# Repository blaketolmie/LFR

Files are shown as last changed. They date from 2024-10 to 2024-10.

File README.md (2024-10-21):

# LFR
ENMT221 Line Following Robot Software  
S2 2024  

## Access to Github
Send me your GitHub username or email so I can grant you collaborater access (so you can make push and pull requests etc)  
[GitHub Desktop](https://github.com/apps/desktop)

## Set up  
Download [MiniCore](https://github.com/MCUdude/MiniCore#how-to-install) and make sure its in the correct folder   
Open [Arduino IDE](https://www.arduino.cc/en/software)  
Select Board - ATmega328 and port  
Go to tools and select preferences and burn bootloader  
+ Board: "ATmega328"  
+ BOD (Brown-out detection): "BOD 2.7V"  
+ Bootloader: "Yes (UART0)"  
+ Clock: "Internal 1 MHz"  
+ Variant: "328P / 328PA"  
+ Programmer: "Atmel-ICE ISP"  
>**Arduino as ISP**: If you have an Arduino board, you can use it to program AVR chips by setting it up as an ISP (In-System Programmer). This is a common and cost-effective method.  
>USBasp: This is a popular and inexpensive USB-based programmer for AVR microcontrollers. It's widely used and works well with AVR GCC.  
>USBtinyISP: Another inexpensive USB programmer. It’s often used with AVR microcontrollers but might be slower than USBasp.  
>AVRISP mkII: This is an official programmer from Atmel (now Microchip) designed for use with AVR microcontrollers. It is a reliable choice if you have access to it.  
>Clock: 9.216 MHz  
>[Arduino Programming](https://docs.arduino.cc/programming/)  
>When coding in Arduino IDE use [Arduino Pins](https://camo.githubusercontent.com/b719fa994f4db0dd95e224fbdd939f93f7b6ba881b3c41e480b4733d4d82b6e6/68747470733a2f2f692e696d6775722e636f6d2f715849456368542e6a7067) in blue  
  
## Arduino_Code
Incorporated  
- Reactive control  
- LEDs  
- Sensors  
- Motors  
- Config file - all #defines for pin and globals  
- Serial communication (println)  
  
NOTE:  
Only one reset button (MOTOR_CONTROL) is available since the RESET button is not connect to the microcontroller in the schematic.  
If sensors are giving random values - check the height from the ground  
Only 3 sensors ended up working hence no PID or bang bang controller  
  
 ## ATMega328P Microcontroller
[ATMega328P Features Datasheet](https://components101.com/microcontrollers/atmega328p-pinout-features-datasheet)  
[ATMega328P Manufacteres Datasheet - register summary on pg8](https://www.jameco.com/Jameco/Products/ProdDS/2139111.pdf)

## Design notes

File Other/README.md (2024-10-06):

# LFR
ENMT221 Line Following Robot Software  
S2 2024  
[NOTE ON COLLABORATION](https://docs.github.com/en/pull-requests/collaborating-with-pull-requests/proposing-changes-to-your-work-with-pull-requests/about-pull-requests)

## ATMega328P Microcontroller
[ATMega328P Datasheet](https://components101.com/microcontrollers/atmega328p-pinout-features-datasheet)  
[Pinout with ADC pins explained](https://www.learningaboutelectronics.com/Articles/Atmega328-pinout.php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,value%3B%20thus%2C%20it%20is%20its%20digital%20correspondent%20value.)
[Full datasheet - register summary on pg8](https://www.jameco.com/Jameco/Products/ProdDS/2139111.pdf)  
## Downloading the bootloader (using Arduino IDE)
[Arduino IDE](https://docs.arduino.cc/software/ide/)    <br>
[MiniCore](https://github.com/MCUdude/MiniCore#how-to-install)  

Using Arduino as ISP since code is in Arduino
>To burn a bootloader using AVR GCC, the choice of programmer depends on the hardware you have available for interfacing with the microcontroller.  
>Here’s a breakdown of the programmers listed in your image and their common uses:  
>  
>**Arduino as ISP**: If you have an Arduino board, you can use it to program AVR chips by setting it up as an ISP (In-System Programmer). This is a common and cost-effective method.  
>USBasp: This is a popular and inexpensive USB-based programmer for AVR microcontrollers. It's widely used and works well with AVR GCC.  
>USBtinyISP: Another inexpensive USB programmer. It’s often used with AVR microcontrollers but might be slower than USBasp.  
>AVRISP mkII: This is an official programmer from Atmel (now Microchip) designed for use with AVR microcontrollers. It is a reliable choice if you have access to it.  
>Clock: 9.216 MHz  

## Programming CHANGE TO ARDUINO PROGRAMMING SINCE EASIER / FASTER
[Arduino Programming](https://docs.arduino.cc/programming/)  
>Serial.print(): Used to print data to the serial monitor without a newline.  
>Serial.println(): Used to print data to the serial monitor with a newline.  
>Serial.println("The value is: " + String(value));

[MiniCore Tips](https://github.com/MCUdude/MiniCore#how-to-install)  
[Embedded C](https://www.learningaboutelectronics.com/EmbeddedC/)  
[AVR](https://github.com/avrdudes/avr-libc)  
**More**  
[Microcontrollers](https://www.eng.auburn.edu/~nelson/courses/elec3040_3050/C%20programming%20for%20embedded%20system%20applications.pdf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)  
[Using ATMEL Studios](https://hardwarebee.com/step-by-step-guide-to-microcontroller-programming/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)  
[tutorial](https://github.com/a5221985/tutorials/blob/master/Embedded_Systems/microcontroller_embedded_c_programming_absolute_beginners.md)  
[other](https://github.com/aman-goel/avr)  
[ENCE260 Richard Claire Code](https://eng-git.canterbury.ac.nz/rmc84/ence260-ucfk4)  
### Pin macros
// Use PIN_PB5 macro to refer to pin PB5 (Arduino pin 13)  
digitalWrite(PIN_PB5, HIGH);

// Results in the exact same compiled code  
digitalWrite(13, HIGH);

### Other things of note with MiniCore
Printf support  
EEPROM option (Electrically Erasable Programmable Read-Only Memory)  
BOD option  
[ADC pins explained](https://www.hackster.io/yeshvanth_muniraj/analog-to-digital-converter-module-of-atmega328p-e255ea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)  
[More on ADCs](https://www.tspi.at/2021/07/15/atmegaavradc.html#:~:text=The%20ATMega328p%20and%20the%20ATMega2560%20offers)  
[Using the ATmega328P ADC Module](https://ece-classes.usc.edu/ee459/library/documents/ADC.pdf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)  
[building circuits](https://www.build-electronic-circuits.com/microcontroller-tutorial-part3/)  

### Example Code


[GitHub Flavored Markdown Spec](https://github.github.com/gfm/)

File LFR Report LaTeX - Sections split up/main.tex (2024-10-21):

\documentclass{article}

% Language setting
% Replace `english' with e.g. `spanish' to change the document language
\usepackage[english]{babel}

% Set page size and margins
% Replace `letterpaper' with `a4paper' for UK/EU standard size
\usepackage[a4paper,top=2cm,bottom=2cm,left=2cm,right=2cm,marginparwidth=2cm]{geometry}

% Useful packages
\usepackage{amsmath}
\usepackage{graphicx}
\usepackage[colorlinks=true, allcolors=black]{hyperref}
\usepackage{bm}
\usepackage{float}  
\usepackage[utf8]{inputenc}
\usepackage{cite}

\usepackage{siunitx}
\usepackage{booktabs}
\usepackage{lipsum}%% a garbage package you don't need except to create examples.
\usepackage{fancyhdr}
\pagestyle{fancy}
\lhead{Wednesday Group A}
\rhead{Line Following Robot}

\renewcommand{\headrulewidth}{0.4pt}
\renewcommand{\footrulewidth}{0.4pt}

\title{%
  \textbf{Line Following Robot} \\
  \large{ENMT221-24S2} \\}
\author{Sarah Tran \\Blake Tolmie \\George Adams \\Michelle Wang }

\begin{document}
\begin{figure}
\centering
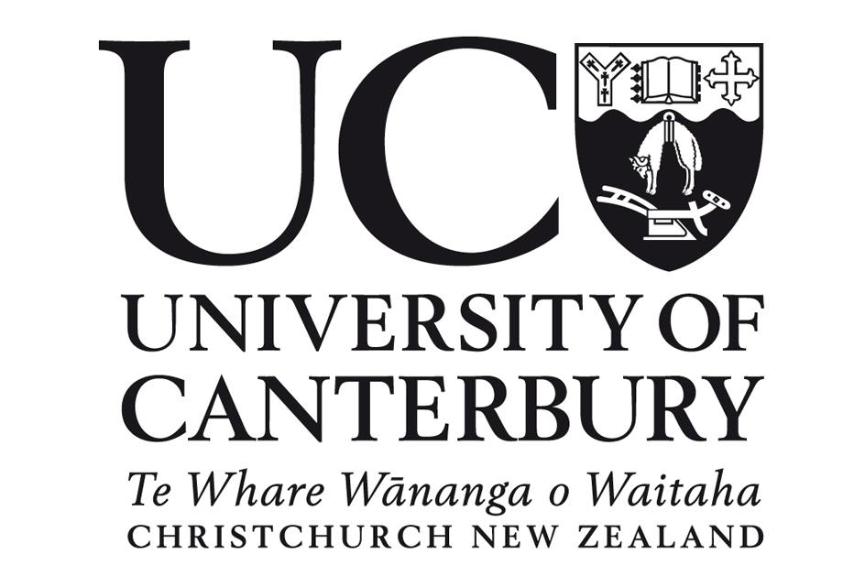
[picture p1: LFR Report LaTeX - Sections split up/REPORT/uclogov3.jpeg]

\end{figure}

\maketitle

\newpage
\begin{abstract}
This report presents the design, development, and performance analysis of a Line Following Robot (LFR), created as part of the ENMT221-24S2 term 4 project. The goal was to design a robot capable of autonomously navigating a course, following a black line on a white background, under strict design and time constraints. The process involved circuit and PCB design, mechanical prototyping, and microcontroller programming. Challenges encountered during the project included sensor board issues, requiring multiple adjustments and iterative design refinements. The final design demonstrated competitive performance, completing the course in 14.939 seconds and coming in $8^{th}$ place out of 36 teams. Despite successful results, further improvements in sensor integration and control algorithms, such as transitioning to PID control, are suggested to enhance the robot's tracking accuracy and speed. This project provided valuable hands-on experience with real-world testing, electronic design, and mechanical assembly.
\end{abstract}

\newpage
\tableofcontents

\newpage
\section{Introduction}
Automation is becoming increasingly prevalent in modern technology, especially with the rise of artificial intelligence and high labour costs. As mechatronics engineering students, it is important to have a strong understanding of the concepts surrounding this. For the term 4 project, we were tasked to design a line-following robot (commonly abbreviated as ‘LFR’) under the given constraints and limitations as specified by the project brief \cite{enmt221_lfr2024}. This process involves circuit design, PCB layout and manufacturing, mechanical design, and microcontroller programming. The aim was to design a robot that completes the provided course (black line on white background) in under 30 seconds. Line following robots have some real-world applications, such as the transportation of medical equipment in large hospitals \cite{kumaresan2017line}, and autonomous public transport \cite{gumus2016line}.  

\include{Contents/methodology.tex}
\include{Contents/results_and_discussion.tex}

\section{Conclusion}
 The Line Following Robot project involved circuit design, PCB layout, mechanical assembly, and control systems. While we encountered challenges, particularly with sensor board malfunctions and feedback control, the robot still performed well, completing the course in 14.939 seconds. By using a reactive control system, we were able to achieve consistent results, though transitioning to a PID control system could improve accuracy and make the robot’s movements smoother. This project emphasized the importance of testing and collaboration to work through design unpredicted errors. Moving forward, further improvements could be made by refining sensor placement, improving the control system, and optimizing the mechanical design. Overall, the project met its objectives and gave us practical experience in combining different areas of mechatronics engineering.

\newpage
\section{references} % Makes it so then it shows up in the table of contents
\bibliographystyle{ieeetr}  % The style of the bibliography (e.g., plain, alpha, etc.) 
\bibliography{Contents/references}

\newpage
\include{Contents/appendix.tex}

\end{document}

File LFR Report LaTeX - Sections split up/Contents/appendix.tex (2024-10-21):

\appendix
\section{Arduino Code for Line Following Robot}
\subsection{Overview}
The code was programmed using Arduino. Only the .ino, .cpp and config.h files are included in Appendix B. For full code including .h files, access the GitHub: \href{https://github.com/blaketolmie/LFR}{https://github.com/blaketolmie/LFR}
\subsection{LFR\_Main.ino}

\begin{figure}[H]
    \centering
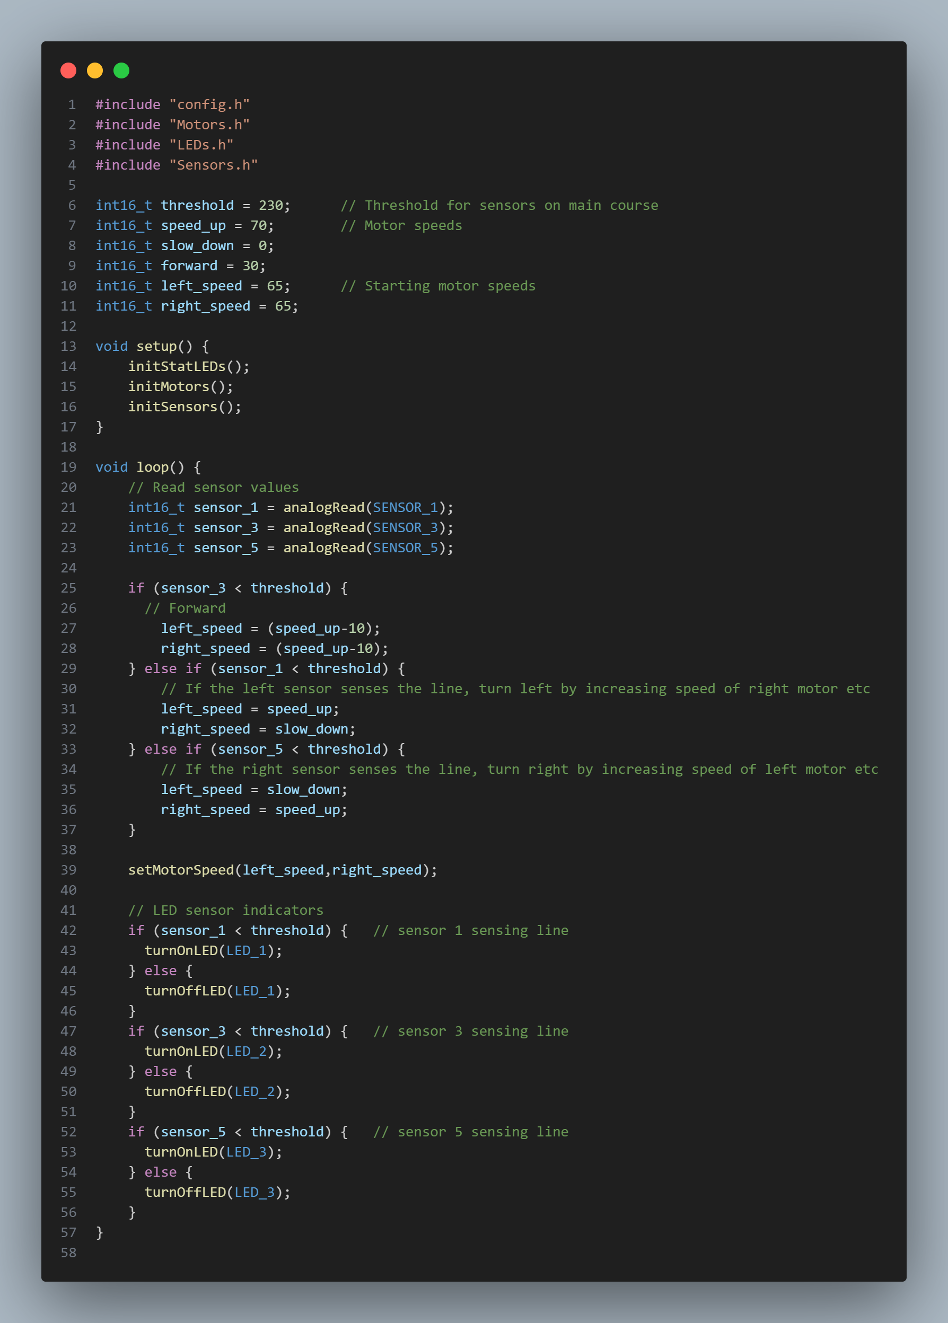
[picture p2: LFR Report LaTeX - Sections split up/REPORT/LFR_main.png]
    
\end{figure}

\subsection{Motors.cpp}

\begin{figure}[H]
    \centering
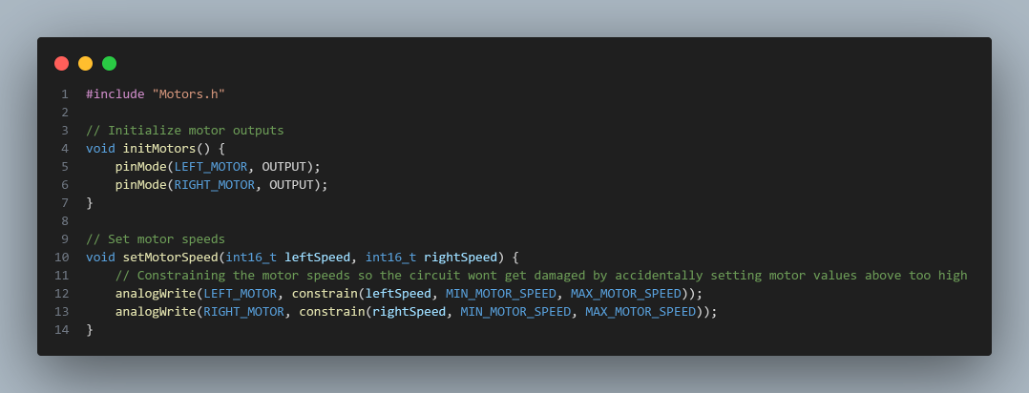
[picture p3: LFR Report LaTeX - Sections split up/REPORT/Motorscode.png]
    
\end{figure}

\subsection{Sensors.cpp}

\begin{figure}[H]
    \centering
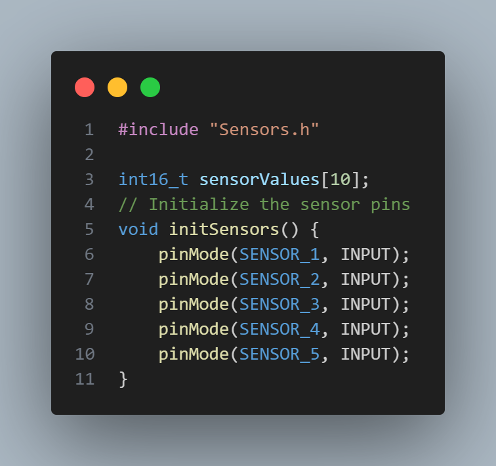
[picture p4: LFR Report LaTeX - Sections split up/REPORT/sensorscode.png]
    
\end{figure}

\subsection{LEDs.cpp}

\begin{figure}[H]
    \centering
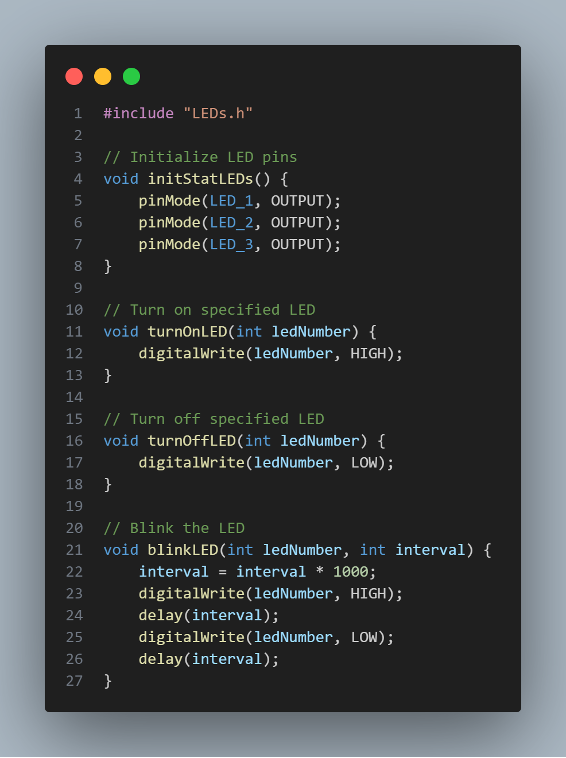
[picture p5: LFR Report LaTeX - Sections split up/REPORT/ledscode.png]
    
\end{figure}

\subsection{Config.h}

\begin{figure}[H]
    \centering
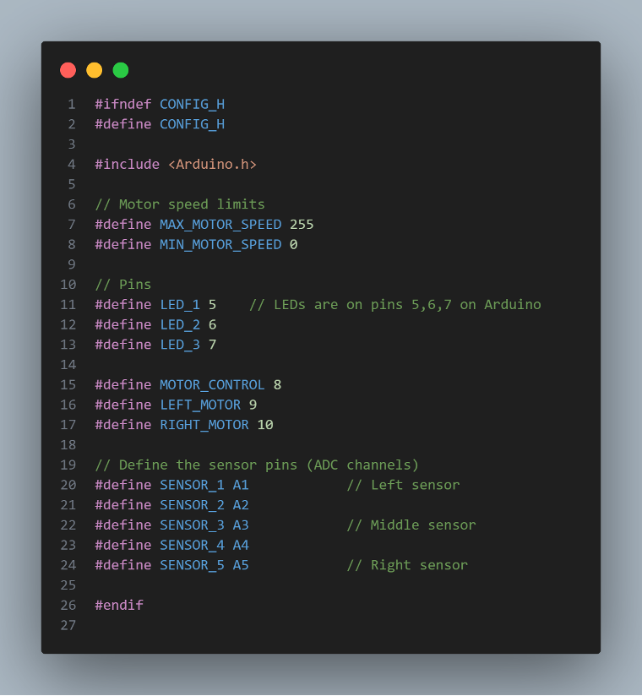
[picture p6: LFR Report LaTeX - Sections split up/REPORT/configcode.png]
    
\end{figure}

\section{Table for LFR Course Times by Sensor Configurations and Weight}
\begin{figure}[H]
    \centering
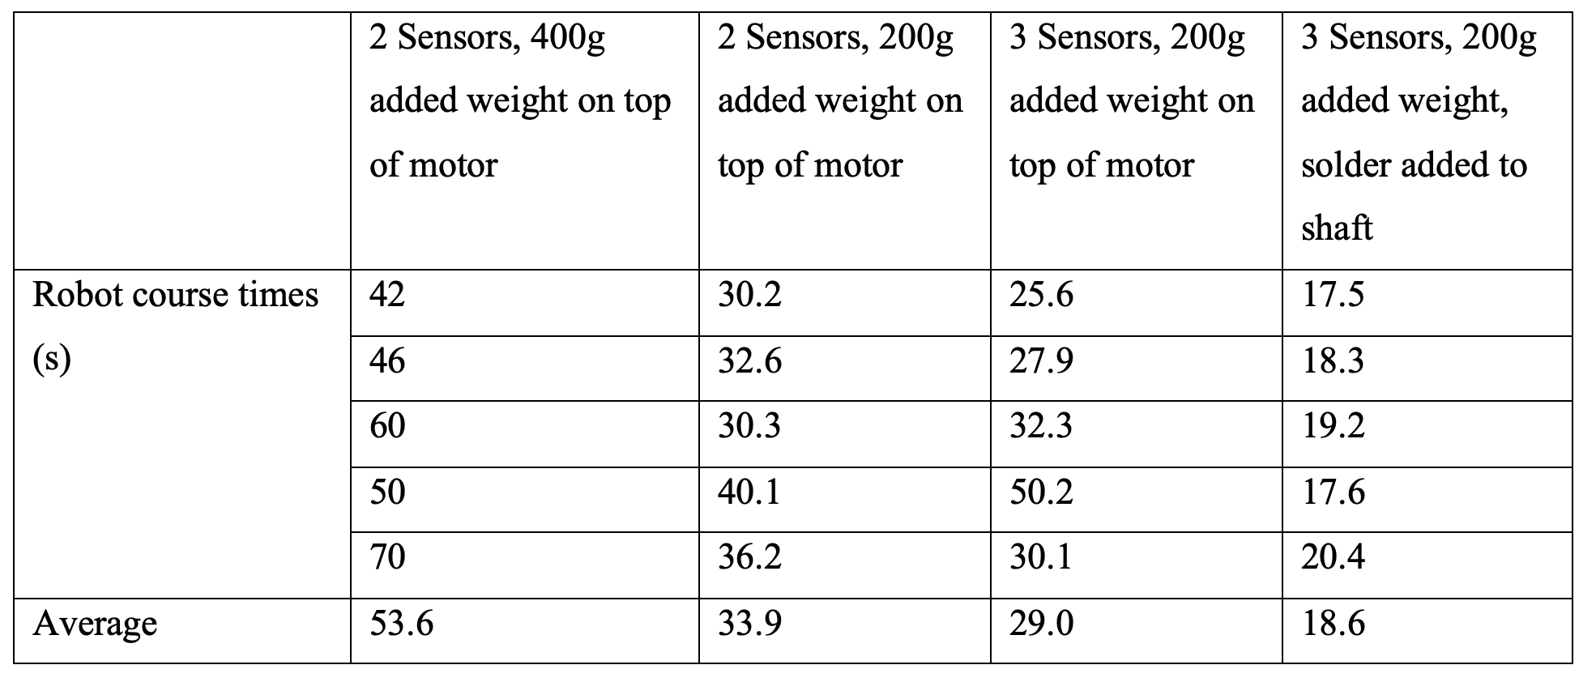
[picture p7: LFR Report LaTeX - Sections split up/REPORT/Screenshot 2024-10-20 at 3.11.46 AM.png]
    
\end{figure}

\section{Allowed Electronic Components}
\begin{figure}[H]
    \centering
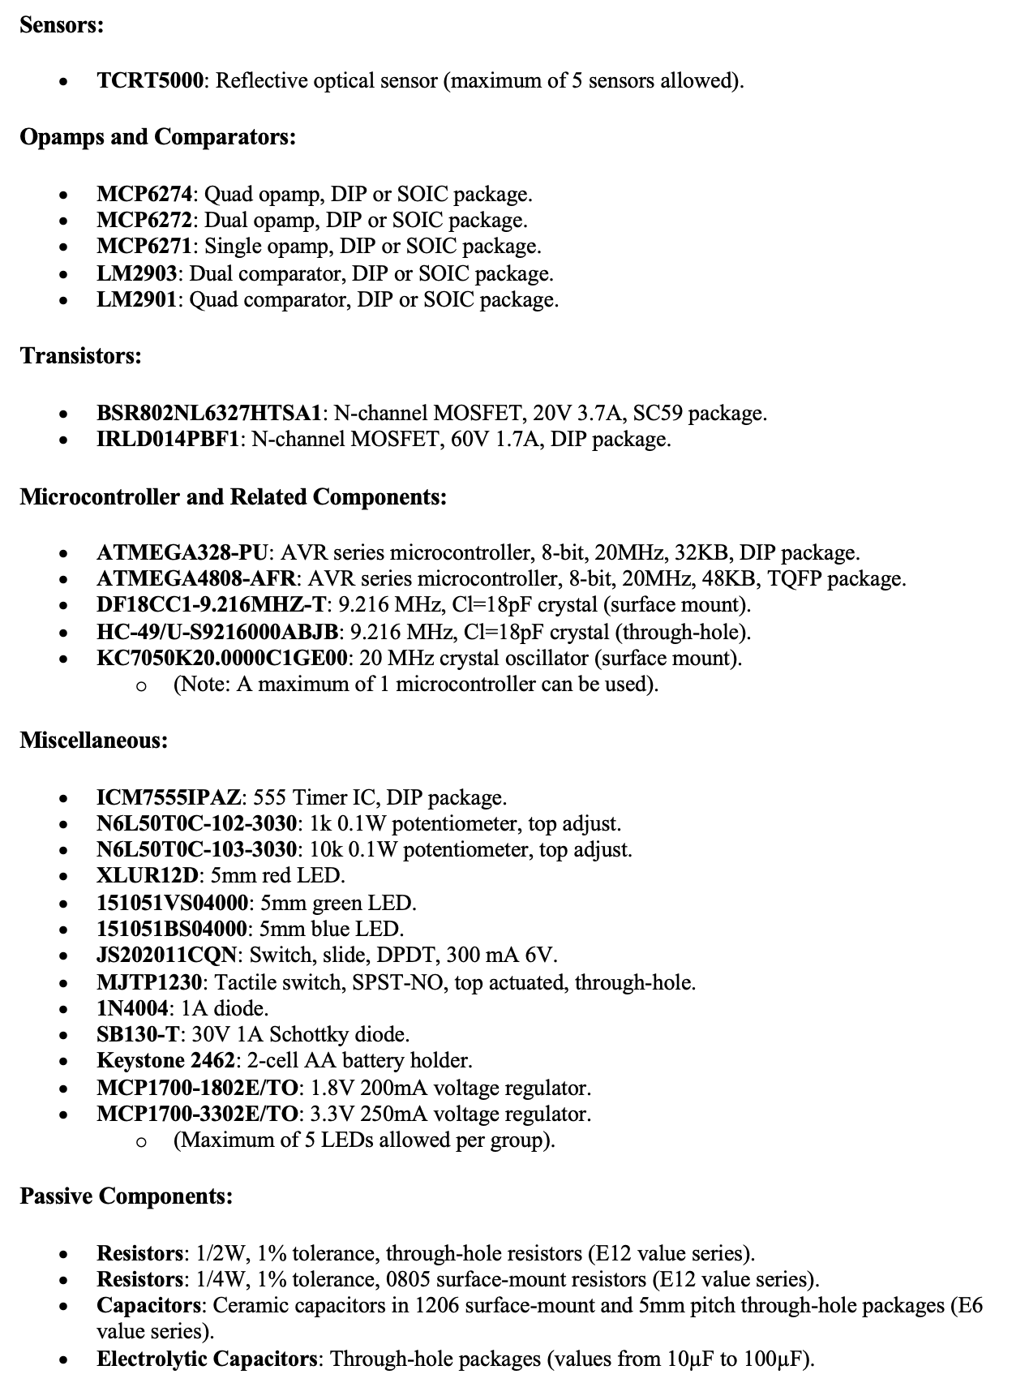
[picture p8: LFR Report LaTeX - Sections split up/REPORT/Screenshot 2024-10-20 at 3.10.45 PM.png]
    
\end{figure}

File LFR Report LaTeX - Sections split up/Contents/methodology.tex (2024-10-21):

\section{Methodology}
\subsection{Circuit Design}
Early in the design process, it was decided that the circuit would be split into a main PCB board and five separate sensor boards. This allowed the sensors to be moved during the mechanical design process, and the distance between them and the ground to be optimised through testing. The design process was split into smaller tasks and delegated to separate teammates. These tasks included motor drivers (Figure \ref{fig:MotorControlCircuit}), power regulation (Figure \ref{fig:VoltageinandReg}), sensors (Figure \ref{fig:SensorSchem}), programming interface and external oscillator (Figure \ref{fig:Crystal}), the microcontroller (Figure \ref{fig:Microcontroller}), and buttons \& LEDs (Figure \ref{fig:RSET}, \ref{fig:led}, and \ref{fig:Motor ON}).
\\

As collaboration was necessary, a major consideration of the design process was the use of the 'labels' function in KiCad, which can link two parts of a schematic together with an invisible virtual wire, to ensure smooth compatibility between systems. Another consideration was the restriction on allowed components (Appendix C), put in place to ensure fairness among teams.

\begin{figure}[H]
    \centering
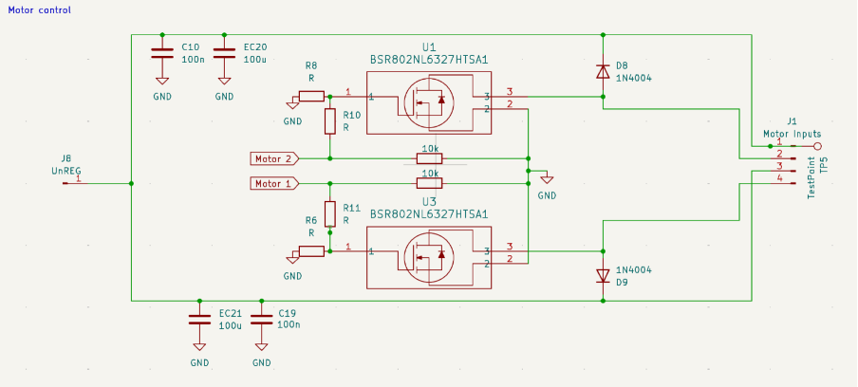
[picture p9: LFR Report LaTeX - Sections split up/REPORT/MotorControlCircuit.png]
    
    \caption{Motor Control Circuit}
    \label{fig:MotorControlCircuit}
\end{figure}

As seen in Figure \ref{fig:MotorControlCircuit}, the motors are controlled by MOSFETs which restrict and allow the flow of power from the unregulated power source through the motors to ground, depending on the input from Motor 1 and 2. These symbols are connected directly to an output capable pin of the microcontroller. As the motors are connected directly to the unregulated power source, capacitors C10, C19, EC20, EC21 are used to filter out unwanted high and low frequencies from the battery source. This use of capacitors is called decoupling. (Note here that C stands for ceramic capacitor which have high capacitance values, while EC stands for electrolytic capacitor which have small values). The motors interface with the circuit through connector J1. Pins 1 and 3 connect directly to the unregulated power source, and to the positive terminals of the motors when assembled. Pins 2 and 4 go to the source pin of the MOSFET and connect to the negative terminals of the motor. As the drain of the MOSFET is connected to ground, when a 3.3V signal comes from the pins of the microcontroller, the unregulated voltage will have a path through the motors to ground, enabling current flow. Flyback diodes D8 and D9 are connected from the MOSFET source pin to the unregulated voltage line, providing a path for back EMF of the motors to cycle through the motor, eventually reducing to 0V and protecting the rest of the circuit from unwanted voltage. 
\\

\begin{figure}[H]
    \centering
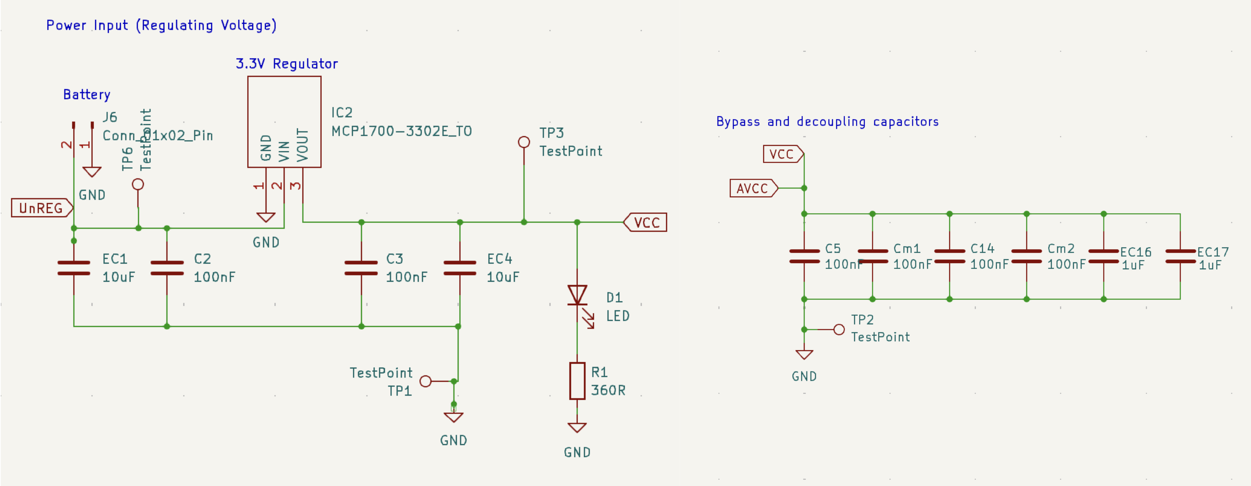
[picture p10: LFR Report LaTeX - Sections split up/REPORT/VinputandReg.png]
    
    \caption{Voltage input and regulation}
    \label{fig:VoltageinandReg}
\end{figure}

Figure \ref{fig:VoltageinandReg} shows how power comes into the circuit. A pack holding four AA batteries was connected to connector J6 labelled ‘Battery’. This was expected to output ~5.5 volts with some fluctuation. This was too high for safe operation of the microcontroller, and with sensitive components such as sensors, we needed some way of reducing the voltage to a manageable level and smoothing it out. The other pin of the battery pack is connected to common ground. After leaving the motor, the unregulated voltage is filtered through decoupling capacitors EC1 and C2 before entering the voltage regulator, IC2. This component outputs VOUT which connects through more decoupling capacitors, C3 and EC4, to the label VCC which is used throughout the circuit as the main power source. Between VCC and ground is a green LED which is used as a ‘power light’ as an easy way to check if the power source is operating correctly. Additionally, there are two test points for unregulated and regulated voltage to help with debugging and circuit analysis. 
\\

\begin{figure}[H]
    \centering
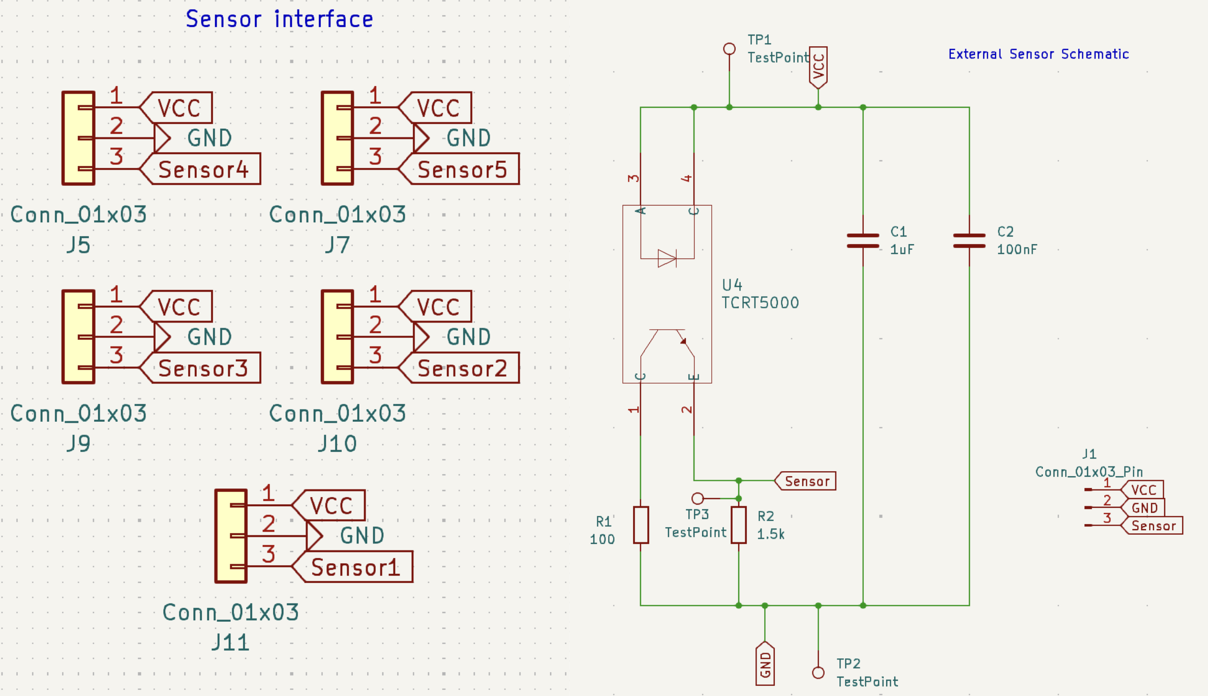
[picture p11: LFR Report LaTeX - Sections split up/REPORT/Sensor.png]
    
    \caption{Sensor board schematic and interface with main board}
    \label{fig:SensorSchem}
\end{figure}

The right section of Figure \ref{fig:SensorSchem} shows the schematic for the external sensor, and the left shows how it interfaces with the main PCB board. J5, 7, 9, 10 are all 3 pin connectors which have traces to VCC, GND and an input capable pin of the microcontroller, denoted by the labels Sensor1-5. These 3 pin connectors are mirrored on the sensor board with J1, allowing wires to be connected directly between the two boards. 
\\

C1 and C2 are decoupling capacitors which take out what little noise there may be from the voltage source. R1 and R2 are current-limiting resistors which prevent a short from output pins of the sensor to ground. It was discovered after the board was manufactured that this schematic was incorrect; Pins 1 and 3 should be connected to VCC, while 2 and 4 should be connected through R1 and R2, respectively, to ground. These modifications would allow current to flow through the BJT and LED inside the sensor and allow it to operate correctly. 
\\

Early in the design process, there was an idea to use an op-amp connected as a Schmitt trigger to convert the analogue output from the sensor to digital directly on the sensor board. After discussion with teaching assistants and other students, it was decided that the complications and possibilities for error of this design outweighed its benefits. 

\begin{figure}[H]
    \centering
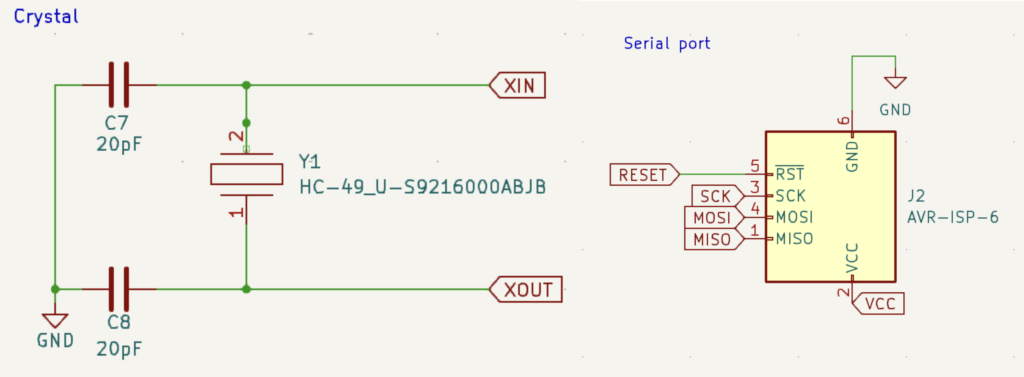
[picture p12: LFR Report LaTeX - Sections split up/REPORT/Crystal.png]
    
    \caption{Programming interface and crystal oscillator}
    \label{fig:Crystal}
\end{figure}

The microcontroller that was selected, the ATMEGA328, was a through-hole-mounted component. The other possibility, the ATMEGA4808, was surface-mount. As surface mount components require extreme delicacy to install correctly, it was decided that the ATMEGA328 would be used as it would ensure ease of assembly. As time constraints were one of the major considerations, this was the deciding factor. The downside of the 328 is that the internal oscillating clock used for timing operations is not ideal and is sometimes unreliable. Due to this, an external oscillating crystal was used. This is shown on the diagram as component Y1 which is connected from the XIN and XOUT pins of the microcontroller, through a set of high-frequency decoupling capacitors to ground. 
\\

The programming interface was implemented through a 6-pin connector, J2. This takes as inputs: A serial clock signal, MOSI and MISO communication channels, RESET, VCC and ground. 

\begin{figure}[H]
    \centering
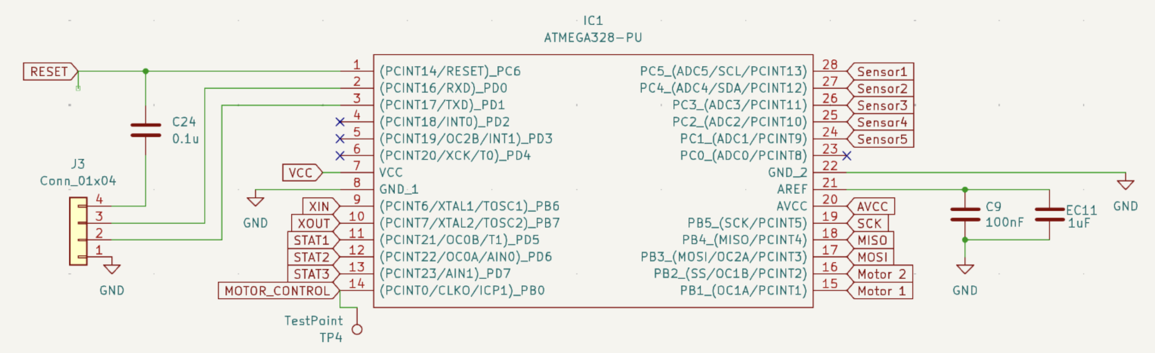
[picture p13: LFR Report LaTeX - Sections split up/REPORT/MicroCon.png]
    
    \caption{Microcontroller}
    \label{fig:Microcontroller}
\end{figure}

\begin{figure}[H]
    \centering
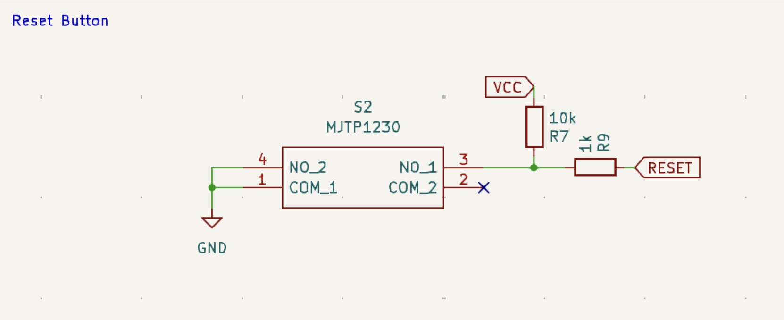
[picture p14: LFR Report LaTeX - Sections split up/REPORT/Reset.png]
    
    \caption{Reset button}
    \label{fig:RSET}
\end{figure}

\begin{figure}[H]
    \centering
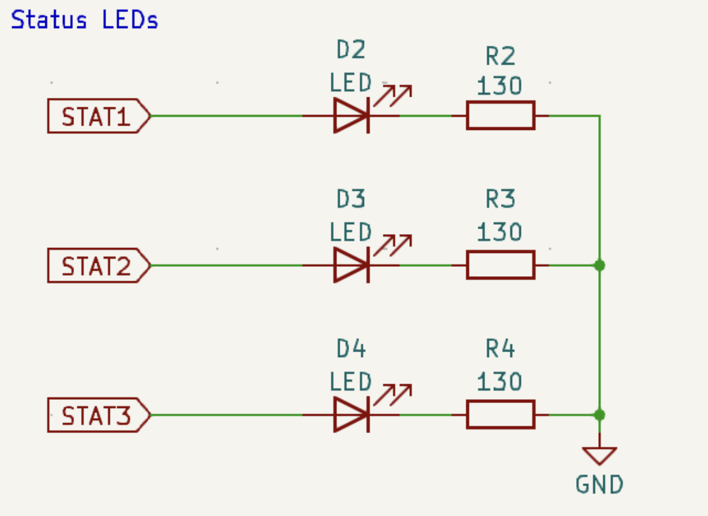
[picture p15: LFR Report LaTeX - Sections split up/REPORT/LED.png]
    
    \caption{Status LEDs}
    \label{fig:led}
\end{figure}

\begin{figure}[H]
    \centering
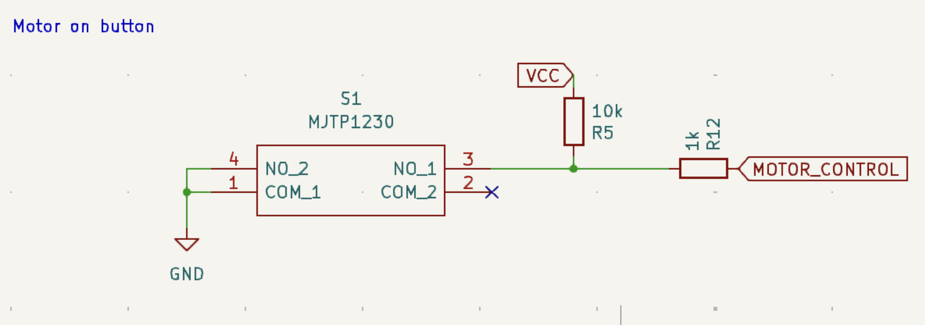
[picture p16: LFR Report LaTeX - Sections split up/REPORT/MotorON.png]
    
    \caption{Motor ON button}
    \label{fig:Motor ON}
\end{figure}

The two buttons - S1 and S2 in Figure \ref{fig:led} and \ref{fig:Motor ON}, were used to turn the motors on and reset the microcontroller, respectively. The VCC flag connects through resistors R7 and R5 to the input pins of the button and through R12 and R9 to ‘active low’ pins of the microcontroller. When the button is not pressed, VCC is able to flow through resistance to the microcontroller, providing it with the full 3.3V of regulated voltage. When the button is pressed, VCC is given a path to ground and shorts past the microcontroller, dropping it to 0V. At least, this is how it was designed. After assembling the board, it was found that the switches used, when pressed, connected pins 4 to 1 and 3 to 2. This meant that the voltage from VCC never had a path to ground, and thus the voltage on the microcontroller pin never dropped to 0. This issue was fixed by connecting a wire between pins 2 and 1, which allowed the button to function correctly. 
\\

The LEDs, shown in the right-hand side of Figure 5, were connected to output-capable pins of the microcontroller, enabling them to be controlled by code. As there was no way of printing outputs to check values of variables, these LEDs were invaluable in the programming stage of the project. 
\\

Finally, the microcontroller with all connected labels is shown in Figure \ref{fig:Microcontroller}. Another communication protocol (that wasn’t used) is seen in J3, which is connected to the RX and TX pins on the microcontroller, enabling a UART communication protocol.  
 
\subsection{PCB Design}
The PCB design for the main board was carried out in several stages. An initial layout (Figure \ref{fig:initpcb}) was completed to get an idea for how components might be arranged. 

\begin{figure}[H]
    \centering
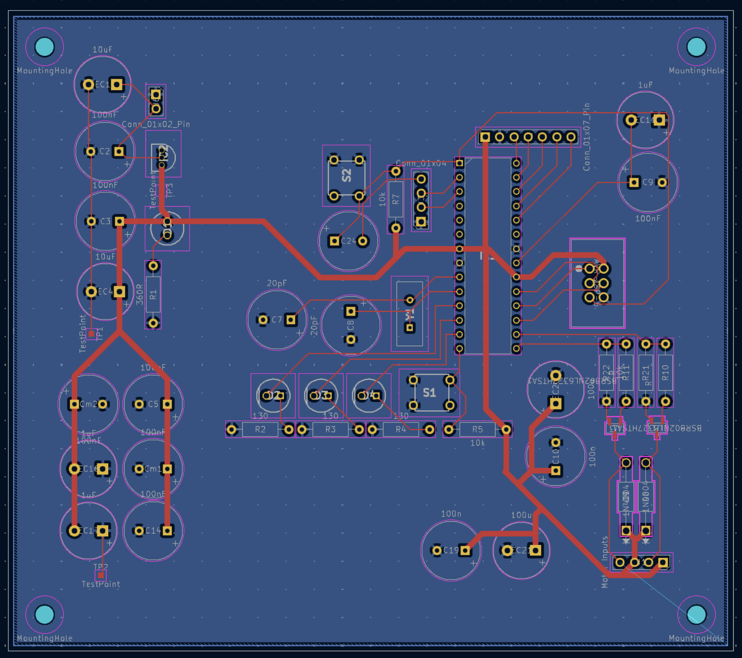
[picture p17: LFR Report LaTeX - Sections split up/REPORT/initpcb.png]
    
    \caption{Initial main PCB design}
    \label{fig:initpcb}
\end{figure}

The initial design took little consideration to the size of the final board. This was mostly an exercise in learning the workflow of KiCAD PCB design and was used to get feedback to complete a second, third and final iteration, which shown in Figure \ref{fig:finalpcb}. 

\begin{figure}[H]
    \centering
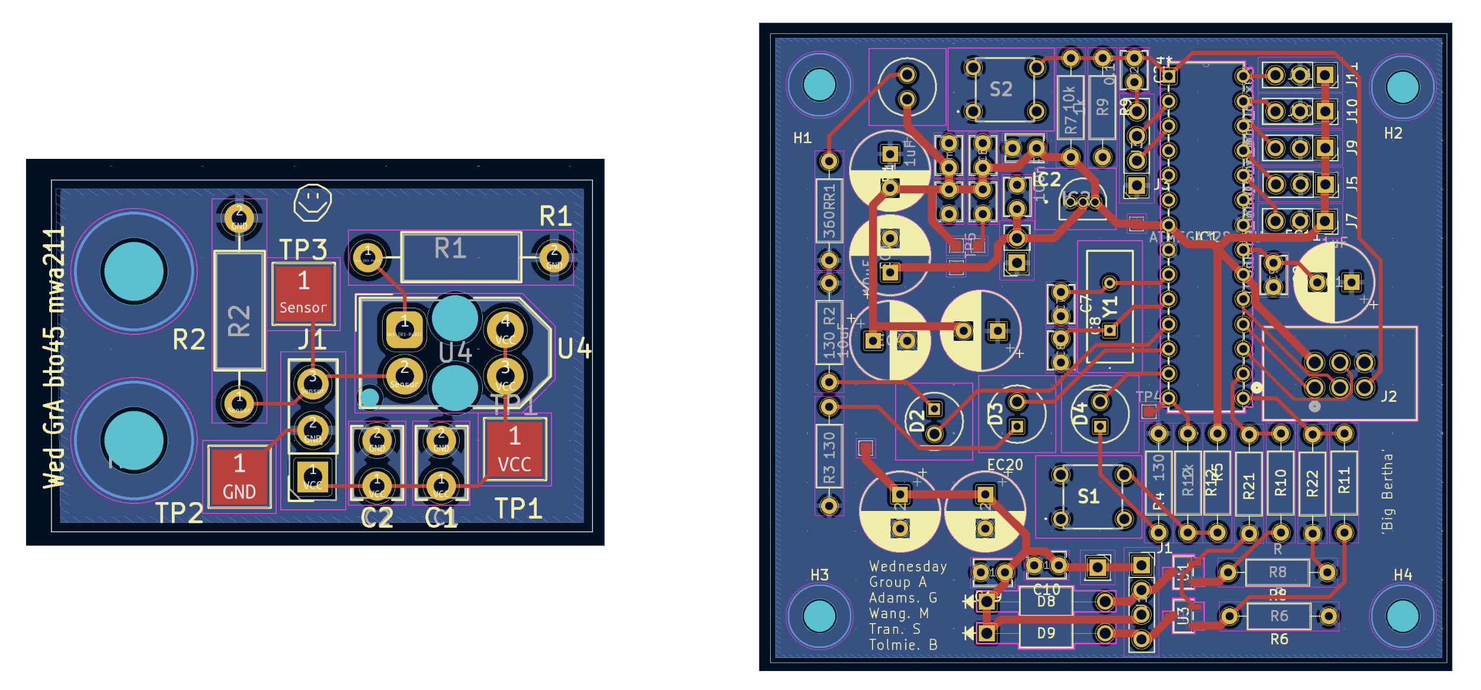
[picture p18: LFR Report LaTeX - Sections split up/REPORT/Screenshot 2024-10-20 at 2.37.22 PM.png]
    
    \caption{Final PCB designs}
    \label{fig:finalpcb}
\end{figure}

There were many considerations that went into the final design. The biggest of which was making traces as short as possible, which cut down on both the size of the board, and the amount of noise induced by electrical and magnetic field coupling. The second was keeping decoupling capacitors as close to the origin of their input signal as possible, to cut down on lag induced by the signal travel time and therefore increase their effectiveness. Finally, the size of the traces was considered, as higher current wires need thicker traces to ensure smooth operation. All wires carrying VCC were .8mm and larger, while all smaller signal carrying traces were left at .4mm. A few issues were encountered in selecting the incorrect footprints, as these were not provided alongside the list of allowable components. Through consultation with teaching assistants, the errors were found and corrected. 
\\

Once the design was completed, the Gerber files were extracted from KiCad and sent to JLC to be manufactured in China. This put pressure on the design process as the factory where they were being made shut down from the 1st to the $8^{th}$ of October. After some delegation and late nights, the completed boards were sent away on the $30^{th}$ of September and were received ready for assembly shortly after. 
\\

Comparatively, the sensor PCB board went through little iterations, the main changes being removing the Schmitt trigger and changing the layout to be smaller. The final design is shown alongside the main board in Figure \ref{fig:finalpcb}. 

\subsection{PCB Board Assembly}
We primarily utilised soldering irons for the PCB board assembly to solder on all the components. There are some key considerations we had to consider to ensure effective soldering.  
\\

We maintained a soldering temperature of 350 °C for all components, as this temperature allows the solder to melt quickly and adhere well to the surfaces being joined, ensuring a strong bond while minimizing excessive heat exposure. Many components, particularly sensitive electronics, can be damaged by higher temperatures, so 350 °C strikes a suitable balance by providing adequate heat for effective soldering while reducing the risk of overheating.  
\\

Additionally, this temperature promotes good flow characteristics, enabling the solder to wick into the gaps between pins and pads effectively. It also reduces the likelihood of oxidation on the surfaces being soldered, resulting in better wetting and bonding.  
\\

Since most components on our board are through-hole type, we utilized conical and chisel tips, depending on the size of the components. Like, we used a fine conical tip to minimize the risk of overheating. These tip shapes facilitate good heat transfer and allow for precision work, making detailed soldering on smaller components easier. The tapered shape of the tips enables access to tight spaces on the PCB without accidentally contacting other components, enhancing control and reducing the likelihood of soldering damage. 
\\

To ensure decent soldering quality, we also kept the soldering tip clean and tinned for efficient heat transfer, minimized the contact time to prevent damage to sensitive components like LEDs, and tested the connections with a multi-meter after soldering to ensure all the components were functioning correctly. 

\subsection{Main board adjustments}

During the testing stage, we encountered that the electrolytic capacitors were not directional which can lead to potential overheat, leakage, or even explosion due to internal pressure buildup. The polarization of these capacitors was random, which compounded the problem.  
\\

Additionally, the LED failed to turn on despite correct pin connections according to the ATMEGA328 micro-controller data sheet and the code for driving the LED. Upon a review of the main PCB layout against the schematic file, it was revealed that the issues were caused by incorrect footprints on the KiCAD PCB layout. In our case, some potential reasons could cause the incorrect footprints for the capacitors and LED. First, component rotation during the placement process may have inadvertently flipped certain components. To address this problem, we need to ensure that we check the orientation during placement and compare it with the schematic file when drawing the traces, making sure that everything is connected to the correct pin.  
\\

Second, incorrect pin mapping may have occurred if the pins on the schematic did not align correctly with the pads in the footprints. This misalignment can potentially lead to improper placement when generating the PCB layout.  
\\

Lastly, the schematic annotation may have played a role in the mismatch between the schematic and layout. It is essential to ensure that any changes made to the schematic file are promptly updated in the PCB layout to maintain consistency between the two. 
\\

Another issue that occurred in the main board assembly was the button connection, stemming from a misunderstanding of its configuration. The button features four pins, consisting of two short pins and two long pins. We incorrectly connected the button to the long pins instead of the short pins, which resulted in the button failing to complete the circuit correctly. To address this issue, we connected a wire between the long pins, so the button is now integrated into the circuit using the short pins. This way, when we press the button, it shorts to ground, allowing the circuit to function as intended. 

\subsection{Sensor board adjustments}
Figure \ref{fig:SensorAdjust} shows the layout of our sensor PCB board, along with the adjustments made based on the testing results. During the testing stage, we used a multimeter to measure the analog readings by testing the sensor pad against the ground pad. It became evident that there was no voltage drop when we covered the sensor, indicating that there was no detection of any objects. This lack of response marked the importance of precise pin connections for the TCRT500 sensor to ensure optimal functionality. 

\begin{figure}[H]
    \centering
    
    \caption{Sensor PCB Board layout adjustment}
    \label{fig:SensorAdjust}
\end{figure}

Upon reviewing the datasheet during the testing stage, we identified that there were some significant misconfigurations in our PCB layout. The Emitter-Cathode (pin 3 in Figure \ref{fig:SensorAdjust}) was not connected correctly with ground, impeding the current flow for the activation of the photo-transistor. To address this issue, we have made several modifications.  
\\

Firstly, we searched the traces connecting the Emitter-Cathode to the power source (VCC) and reconnected it to ground using a jumping wire. This change would allow proper current flow when the phototransistor is activated. 

Next, we scratched the traces between the Emitter-Cathode and Emitter-Anode, then connected the Emitter-Anode (pin 4 in Figure \ref{fig:SensorAdjust}) to VCC test pad with a 3.3k resistor. This modification provided a proper voltage drop and limited excessive current through the phototransistor. 

Additionally, we cut the connection between resistor R1 and the Phototransistor-Emitter (Pin 1) and reconnected the Phototransistor-Emitter to the VCC test pad using a 47 Ohms resistor. This adjustment ensures that the phototransistor is driven high when not active, facilitating correct circuit operation.  

Finally, we connected the Phototransistor-Collector (pin 2 in Figure \ref{fig:SensorAdjust}) to a pull-up resistor R2, leading to the positive voltage source. This would ensure a stable high signal when the phototransistor is off, preventing false readings.  
\\

These modifications are essential for restoring the functionality of TCRT500, ensuring the accurate detection capabilities for the Line following robot. 

\subsection{Mechanical design}
For the mechanical build, the following materials are allowed: 

\begin{itemize}  
    \item 100g of 3D printed PLA to be 3D printed.   
    \item Perspex sheet 4.5 mm thick with a bounding box of 200 × 200 mm.   
    \item M3 screws, washers, and nuts. 
    \item Rubber bands, thread. 
    \item Purely decorative elements. 
    \item Multicomp MM10 DC motor.
    \item Multicomp MM28 DC motor.
\end{itemize}  
The robot is fully printed from PLA using Bambu 3D printers from the University of Canterbury Mechanical Engineering Department. This method allows for rapid ideation and prototyping, allowing the design to be fine-tuned throughout the project.  

\subsubsection{Main Body}
The main body must serve as a base to attach the main PCB, sensor PCB modules, battery packs, wheels, and motor hinges. Initially, the main body was planned to be laser cut from an A3 Perspex acrylic sheet so that the 100g of printed PLA can be allocated to solely the wheels and motor hinges. The weight limit, however, was not an issue, and PLA was used for the main body as it allowed for decorative details and rapid prototyping (access to 3D printing is 24/7).  
\\

As shown in Figure \ref{fig:MainBod}, the initial design intended to have a raised platform for the PCB, housing the power source underneath. After printing and testing this, it was discovered that the power source is better mounted on the underside of the body, leaving much more room on top. This is more optimal as it maintains the proximity of the batteries to the PCB, reducing the risk of stray inductance/noise in the circuit, as well as lowering the centre of mass which increases the efficiency of the dynamics. 
\\

The final design also included a lot more 3M holes. This decreased the mass of the robot, but more importantly, it allowed more customisation and flexibility during the latter stages when the robot was being assembled and tested.  

\begin{figure}[H]
    \centering
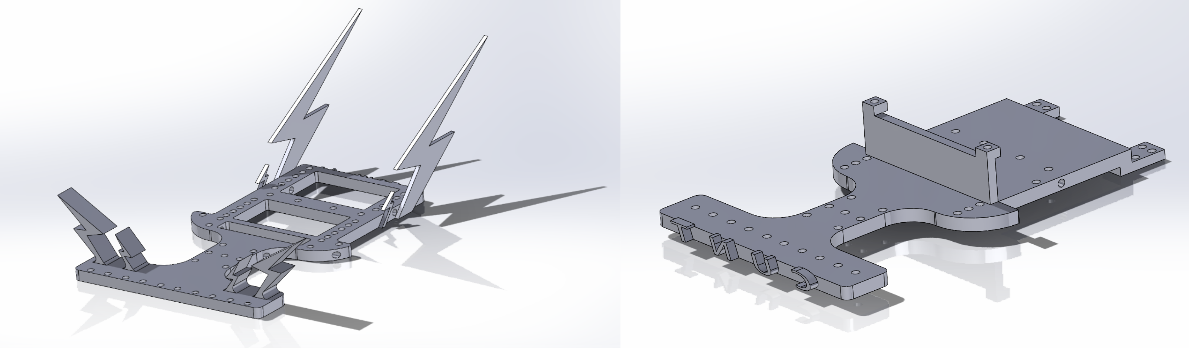
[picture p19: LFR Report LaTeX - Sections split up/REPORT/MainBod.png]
    
    \caption{Main body isometric view – Final vs. Initial design}
    \label{fig:MainBod}
\end{figure}

\subsubsection{Motor hinge}
The motor hinge design was kept basic as shown in Figure \ref{fig:Motorhinge}, with the motor holding being 0.1mm larger than the motor diameter dimension to create a transition fit that tightly holds the motor in place. To keep the motor from sliding out, the bottom was dimensioned 1mm smaller, this ensured stability yet easy access to the wiring pins. Lightning bolt extrusions were added to match the aesthetic theme of the main body. The motors spin the wheels via direct contact drive, so the lightning bolts also served as a ledge to hold a counterweight we implemented in the final design. This counterweight was made from our prototype wheels as a casing, and broken DC motors as weights; this reduced wasted material. 

\begin{figure}[H]
    \centering
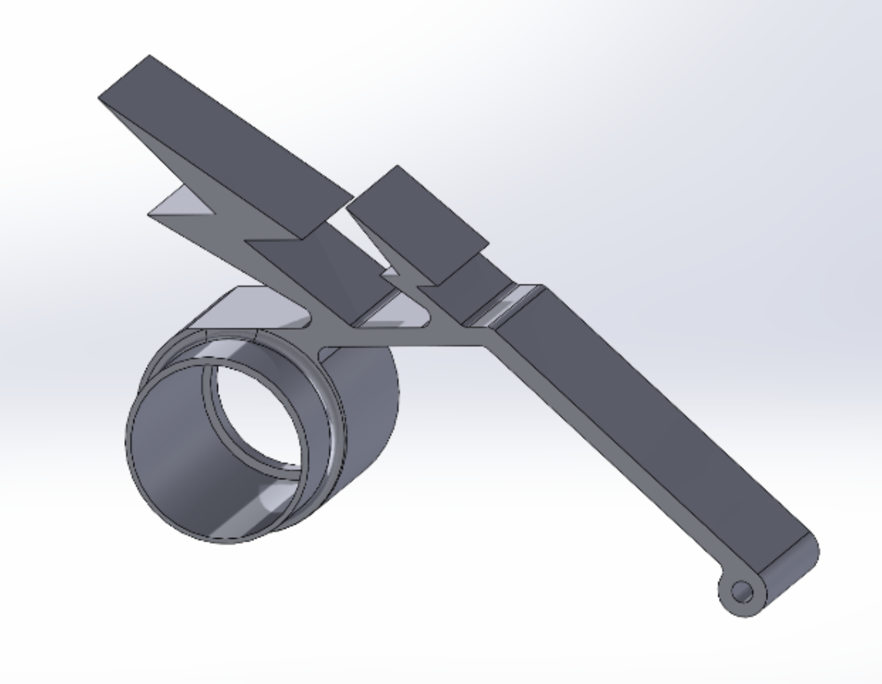
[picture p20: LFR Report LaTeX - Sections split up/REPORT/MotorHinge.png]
    
    \caption{Motor Hinge isometric view}
    \label{fig:Motorhinge}
\end{figure}

\subsubsection{Wheels}
Two variations of the wheel design were manufactured, thin and thick as shown on the left and right of Figure \ref{fig:Wheels} respectively. 50, 55, 60, 65, and 70mm diameter dimensions were trialled throughout the project. The final wheel on the robot was a 55mm thick wheel. The smaller diameter had a smaller moment of inertia, which required less torque to rotate whilst still being large enough so that the motor hinges did not interfere with the electronic components of the main PCB. 

\begin{figure}[H]
    \centering
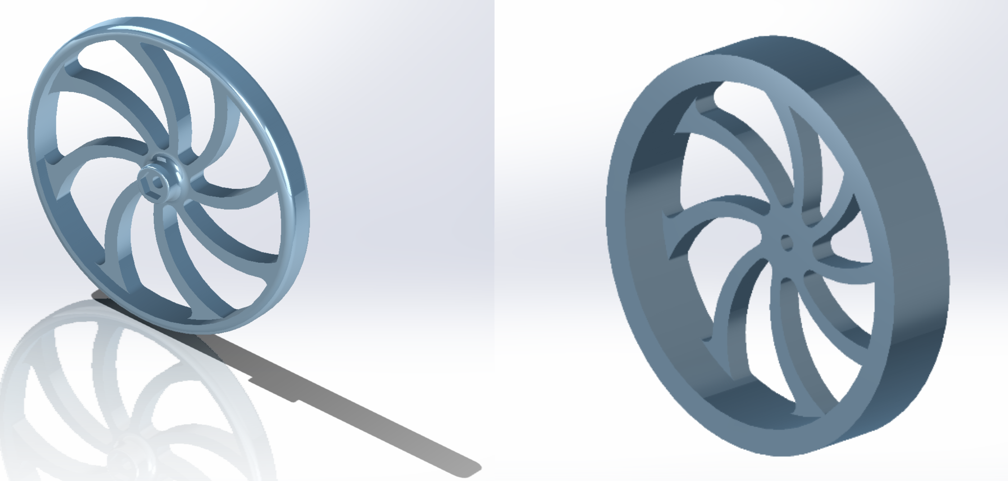
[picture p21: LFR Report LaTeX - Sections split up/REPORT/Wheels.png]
    
    \caption{Thick and thin wheel design variations isometric view}
    \label{fig:Wheels}
\end{figure}

\subsection{Software}
A reactive controller was made using Arduino programming, code in Appendix A. The reactive control depended on the immediate feedback of 3 sensors, left, centre, and right, where each sensor was compared against a threshold value to detect if the sensor was on the line. The robot was placed with the line central to the centre sensor. The robot would turn left if the right sensor detected the line, right if the left sensor detected the line, and forward if the centre sensor detected the line. This closed-loop control system minimized the error of the distance from the line, providing a simple, robust and responsive method of following the line.

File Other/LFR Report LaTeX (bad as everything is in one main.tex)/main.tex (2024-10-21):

\documentclass{article}

% Language setting
% Replace `english' with e.g. `spanish' to change the document language
\usepackage[english]{babel}

% Set page size and margins
% Replace `letterpaper' with `a4paper' for UK/EU standard size
\usepackage[a4paper,top=2cm,bottom=2cm,left=2cm,right=2cm,marginparwidth=2cm]{geometry}

% Useful packages
\usepackage{amsmath}
\usepackage{graphicx}
\usepackage[colorlinks=true, allcolors=black]{hyperref}
\usepackage{bm}
\usepackage{float}  
\usepackage[utf8]{inputenc}
\usepackage{cite}

\usepackage{siunitx}
\usepackage{booktabs}
\usepackage{lipsum}%% a garbage package you don't need except to create examples.
\usepackage{fancyhdr}
\pagestyle{fancy}
\lhead{Wednesday Group A}
\rhead{Line Following Robot}

\renewcommand{\headrulewidth}{0.4pt}
\renewcommand{\footrulewidth}{0.4pt}

\title{%
  \textbf{Line Following Robot} \\
  \large{ENMT221-24S2} \\}
\author{Sarah Tran \\Blake Tolmie \\George Adams \\Michelle Wang }

\begin{document}
\begin{figure}
\centering

\end{figure}

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

\end{abstract}
\newpage
\tableofcontents
\newpage

\section{Introduction}

Automation is becoming increasingly prevalent in modern technology, especially with the rise of artificial intelligence and high labour costs. As mechatronics engineering students, it is important to have a strong understanding of the concepts surrounding this. For the term 4 project, we were tasked to design a line-following robot (commonly abbreviated as ‘LFR’) under the given constraints and limitations as specified by the project brief \cite{enmt221_lfr2024}. This process involves circuit design, PCB layout and manufacturing, mechanical design, and microcontroller programming. The aim was to design a robot that completes the provided course (black line on white background) in under 30 seconds. Line following robots have some real-world applications, such as the transportation of medical equipment in large hospitals \cite{kumaresan2017line}, and autonomous public transport \cite{gumus2016line}.  

\section{Methodology}
\subsection{Circuit Design}
Early in the design process, it was decided that the circuit would be split into a main PCB board and five separate sensor boards. This allowed the sensors to be moved during the mechanical design process, and the distance between them and the ground to be optimised through testing. The design process was split into smaller tasks and delegated to separate teammates. These tasks included motor drivers (Figure \ref{fig:MotorControlCircuit}), power regulation (Figure \ref{fig:VoltageinandReg}), sensors (Figure \ref{fig:SensorSchem}), programming interface and external oscillator (Figure \ref{fig:Crystal}), the microcontroller (Figure \ref{fig:Microcontroller}), and buttons \& LEDs (Figure \ref{fig:RSET}, \ref{fig:led}, and \ref{fig:Motor ON}).
\\

As collaboration was necessary, a major consideration of the design process was the use of the 'labels' function in KiCad, which can link two parts of a schematic together with an invisible virtual wire, to ensure smooth compatibility between systems. Another consideration was the restriction on allowed components (Appendix C), put in place to ensure fairness among teams.

\begin{figure}[H]
    \centering
    
    \caption{Motor Control Circuit}
    \label{fig:MotorControlCircuit}
\end{figure}

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

\begin{figure}[H]
    \centering
    
    \caption{Voltage input and regulation}
    \label{fig:VoltageinandReg}
\end{figure}

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

\begin{figure}[H]
    \centering
    
    \caption{Sensor board schematic and interface with main board}
    \label{fig:SensorSchem}
\end{figure}

The right section of Figure \ref{fig:SensorSchem} shows the schematic for the external sensor, and the left shows how it interfaces with the main PCB board. J5, 7, 9, 10 are all 3 pin connectors which have traces to VCC, GND and an input capable pin of the microcontroller, denoted by the labels Sensor1-5. These 3 pin connectors are mirrored on the sensor board with J1, allowing wires to be connected directly between the two boards. 
\\

C1 and C2 are decoupling capacitors which take out what little noise there may be from the voltage source. R1 and R2 are current-limiting resistors which prevent a short from output pins of the sensor to ground. It was discovered after the board was manufactured that this schematic was incorrect; Pins 1 and 3 should be connected to VCC, while 2 and 4 should be connected through R1 and R2, respectively, to ground. These modifications would allow current to flow through the BJT and LED inside the sensor and allow it to operate correctly. 
\\

Early in the design process, there was an idea to use an op-amp connected as a Schmitt trigger to convert the analogue output from the sensor to digital directly on the sensor board. After discussion with teaching assistants and other students, it was decided that the complications and possibilities for error of this design outweighed its benefits. 

\begin{figure}[H]
    \centering
    
    \caption{Programming interface and crystal oscillator}
    \label{fig:Crystal}
\end{figure}

The microcontroller that was selected, the ATMEGA328, was a through-hole-mounted component. The other possibility, the ATMEGA4808, was surface-mount. As surface mount components require extreme delicacy to install correctly, it was decided that the ATMEGA328 would be used as it would ensure ease of assembly. As time constraints were one of the major considerations, this was the deciding factor. The downside of the 328 is that the internal oscillating clock used for timing operations is not ideal and is sometimes unreliable. Due to this, an external oscillating crystal was used. This is shown on the diagram as component Y1 which is connected from the XIN and XOUT pins of the microcontroller, through a set of high-frequency decoupling capacitors to ground. 
\\

The programming interface was implemented through a 6-pin connector, J2. This takes as inputs: A serial clock signal, MOSI and MISO communication channels, RESET, VCC and ground. 

\begin{figure}[H]
    \centering
    
    \caption{Microcontroller}
    \label{fig:Microcontroller}
\end{figure}

\begin{figure}[H]
    \centering
    
    \caption{Reset button}
    \label{fig:RSET}
\end{figure}

\begin{figure}[H]
    \centering
    
    \caption{Status LEDs}
    \label{fig:led}
\end{figure}

\begin{figure}[H]
    \centering
    
    \caption{Motor ON button}
    \label{fig:Motor ON}
\end{figure}

The two buttons - S1 and S2 in Figure \ref{fig:led} and \ref{fig:Motor ON}, were used to turn the motors on and reset the microcontroller, respectively. The VCC flag connects through resistors R7 and R5 to the input pins of the button and through R12 and R9 to ‘active low’ pins of the microcontroller. When the button is not pressed, VCC is able to flow through resistance to the microcontroller, providing it with the full 3.3V of regulated voltage. When the button is pressed, VCC is given a path to ground and shorts past the microcontroller, dropping it to 0V. At least, this is how it was designed. After assembling the board, it was found that the switches used, when pressed, connected pins 4 to 1 and 3 to 2. This meant that the voltage from VCC never had a path to ground, and thus the voltage on the microcontroller pin never dropped to 0. This issue was fixed by connecting a wire between pins 2 and 1, which allowed the button to function correctly. 
\\

The LEDs, shown in the right-hand side of Figure 5, were connected to output-capable pins of the microcontroller, enabling them to be controlled by code. As there was no way of printing outputs to check values of variables, these LEDs were invaluable in the programming stage of the project. 
\\

Finally, the microcontroller with all connected labels is shown in Figure \ref{fig:Microcontroller}. Another communication protocol (that wasn’t used) is seen in J3, which is connected to the RX and TX pins on the microcontroller, enabling a UART communication protocol.  
 
\subsection{PCB Design}
The PCB design for the main board was carried out in several stages. An initial layout (Figure \ref{fig:initpcb}) was completed to get an idea for how components might be arranged. 

\begin{figure}[H]
    \centering
    
    \caption{Initial main PCB design}
    \label{fig:initpcb}
\end{figure}

The initial design took little consideration to the size of the final board. This was mostly an exercise in learning the workflow of KiCAD PCB design and was used to get feedback to complete a second, third and final iteration, which shown in Figure \ref{fig:finalpcb}. 

\begin{figure}[H]
    \centering
    
    \caption{Final PCB designs}
    \label{fig:finalpcb}
\end{figure}

There were many considerations that went into the final design. The biggest of which was making traces as short as possible, which cut down on both the size of the board, and the amount of noise induced by electrical and magnetic field coupling. The second was keeping decoupling capacitors as close to the origin of their input signal as possible, to cut down on lag induced by the signal travel time and therefore increase their effectiveness. Finally, the size of the traces was considered, as higher current wires need thicker traces to ensure smooth operation. All wires carrying VCC were .8mm and larger, while all smaller signal carrying traces were left at .4mm. A few issues were encountered in selecting the incorrect footprints, as these were not provided alongside the list of allowable components. Through consultation with teaching assistants, the errors were found and corrected. 
\\

Once the design was completed, the Gerber files were extracted from KiCad and sent to JLC to be manufactured in China. This put pressure on the design process as the factory where they were being made shut down from the 1st to the $8^{th}$ of October. After some delegation and late nights, the completed boards were sent away on the $30^{th}$ of September and were received ready for assembly shortly after. 
\\

Comparatively, the sensor PCB board went through little iterations, the main changes being removing the Schmitt trigger and changing the layout to be smaller. The final design is shown alongside the main board in Figure \ref{fig:finalpcb}. 

\subsection{PCB Board Assembly}
We primarily utilised soldering irons for the PCB board assembly to solder on all the components. There are some key considerations we had to consider to ensure effective soldering.  
\\

We maintained a soldering temperature of 350 °C for all components, as this temperature allows the solder to melt quickly and adhere well to the surfaces being joined, ensuring a strong bond while minimizing excessive heat exposure. Many components, particularly sensitive electronics, can be damaged by higher temperatures, so 350 °C strikes a suitable balance by providing adequate heat for effective soldering while reducing the risk of overheating.  
\\

Additionally, this temperature promotes good flow characteristics, enabling the solder to wick into the gaps between pins and pads effectively. It also reduces the likelihood of oxidation on the surfaces being soldered, resulting in better wetting and bonding.  
\\

Since most components on our board are through-hole type, we utilized conical and chisel tips, depending on the size of the components. Like, we used a fine conical tip to minimize the risk of overheating. These tip shapes facilitate good heat transfer and allow for precision work, making detailed soldering on smaller components easier. The tapered shape of the tips enables access to tight spaces on the PCB without accidentally contacting other components, enhancing control and reducing the likelihood of soldering damage. 
\\

To ensure decent soldering quality, we also kept the soldering tip clean and tinned for efficient heat transfer, minimized the contact time to prevent damage to sensitive components like LEDs, and tested the connections with a multi-meter after soldering to ensure all the components were functioning correctly. 

\subsection{Main board adjustments}

During the testing stage, we encountered that the electrolytic capacitors were not directional which can lead to potential overheat, leakage, or even explosion due to internal pressure buildup. The polarization of these capacitors was random, which compounded the problem.  
\\

Additionally, the LED failed to turn on despite correct pin connections according to the ATMEGA328 micro-controller data sheet and the code for driving the LED. Upon a review of the main PCB layout against the schematic file, it was revealed that the issues were caused by incorrect footprints on the KiCAD PCB layout. In our case, some potential reasons could cause the incorrect footprints for the capacitors and LED. First, component rotation during the placement process may have inadvertently flipped certain components. To address this problem, we need to ensure that we check the orientation during placement and compare it with the schematic file when drawing the traces, making sure that everything is connected to the correct pin.  
\\

Second, incorrect pin mapping may have occurred if the pins on the schematic did not align correctly with the pads in the footprints. This misalignment can potentially lead to improper placement when generating the PCB layout.  
\\

Lastly, the schematic annotation may have played a role in the mismatch between the schematic and layout. It is essential to ensure that any changes made to the schematic file are promptly updated in the PCB layout to maintain consistency between the two. 
\\

Another issue that occurred in the main board assembly was the button connection, stemming from a misunderstanding of its configuration. The button features four pins, consisting of two short pins and two long pins. We incorrectly connected the button to the long pins instead of the short pins, which resulted in the button failing to complete the circuit correctly. To address this issue, we connected a wire between the long pins, so the button is now integrated into the circuit using the short pins. This way, when we press the button, it shorts to ground, allowing the circuit to function as intended. 

\subsection{Sensor board adjustments}
Figure \ref{fig:SensorAdjust} shows the layout of our sensor PCB board, along with the adjustments made based on the testing results. During the testing stage, we used a multimeter to measure the analog readings by testing the sensor pad against the ground pad. It became evident that there was no voltage drop when we covered the sensor, indicating that there was no detection of any objects. This lack of response marked the importance of precise pin connections for the TCRT500 sensor to ensure optimal functionality. 

\begin{figure}[H]
    \centering
    
    \caption{Sensor PCB Board layout adjustment}
    \label{fig:SensorAdjust}
\end{figure}

Upon reviewing the datasheet during the testing stage, we identified that there were some significant misconfigurations in our PCB layout. The Emitter-Cathode (pin 3 in Figure \ref{fig:SensorAdjust}) was not connected correctly with ground, impeding the current flow for the activation of the photo-transistor. To address this issue, we have made several modifications.  
\\

Firstly, we searched the traces connecting the Emitter-Cathode to the power source (VCC) and reconnected it to ground using a jumping wire. This change would allow proper current flow when the phototransistor is activated. 

Next, we scratched the traces between the Emitter-Cathode and Emitter-Anode, then connected the Emitter-Anode (pin 4 in Figure \ref{fig:SensorAdjust}) to VCC test pad with a 3.3k resistor. This modification provided a proper voltage drop and limited excessive current through the phototransistor. 

Additionally, we cut the connection between resistor R1 and the Phototransistor-Emitter (Pin 1) and reconnected the Phototransistor-Emitter to the VCC test pad using a 47 Ohms resistor. This adjustment ensures that the phototransistor is driven high when not active, facilitating correct circuit operation.  

Finally, we connected the Phototransistor-Collector (pin 2 in Figure \ref{fig:SensorAdjust}) to a pull-up resistor R2, leading to the positive voltage source. This would ensure a stable high signal when the phototransistor is off, preventing false readings.  
\\

These modifications are essential for restoring the functionality of TCRT500, ensuring the accurate detection capabilities for the Line following robot. 

\subsection{Mechanical design}
For the mechanical build, the following materials are allowed: 

\begin{itemize}  
    \item 100g of 3D printed PLA to be 3D printed.   
    \item Perspex sheet 4.5 mm thick with a bounding box of 200 × 200 mm.   
    \item M3 screws, washers, and nuts. 
    \item Rubber bands, thread. 
    \item Purely decorative elements. 
    \item Multicomp MM10 DC motor.
    \item Multicomp MM28 DC motor.
\end{itemize}  
The robot is fully printed from PLA using Bambu 3D printers from the University of Canterbury Mechanical Engineering Department. This method allows for rapid ideation and prototyping, allowing the design to be fine-tuned throughout the project.  

\subsubsection{Main Body}
The main body must serve as a base to attach the main PCB, sensor PCB modules, battery packs, wheels, and motor hinges. Initially, the main body was planned to be laser cut from an A3 Perspex acrylic sheet so that the 100g of printed PLA can be allocated to solely the wheels and motor hinges. The weight limit, however, was not an issue, and PLA was used for the main body as it allowed for decorative details and rapid prototyping (access to 3D printing is 24/7).  
\\

As shown in Figure \ref{fig:MainBod}, the initial design intended to have a raised platform for the PCB, housing the power source underneath. After printing and testing this, it was discovered that the power source is better mounted on the underside of the body, leaving much more room on top. This is more optimal as it maintains the proximity of the batteries to the PCB, reducing the risk of stray inductance/noise in the circuit, as well as lowering the centre of mass which increases the efficiency of the dynamics. 
\\

The final design also included a lot more 3M holes. This decreased the mass of the robot, but more importantly, it allowed more customisation and flexibility during the latter stages when the robot was being assembled and tested.  

\begin{figure}[H]
    \centering
    
    \caption{Main body isometric view – Final vs. Initial design}
    \label{fig:MainBod}
\end{figure}

\subsubsection{Motor hinge}
The motor hinge design was kept basic as shown in Figure \ref{fig:Motorhinge}, with the motor holding being 0.1mm larger than the motor diameter dimension to create a transition fit that tightly holds the motor in place. To keep the motor from sliding out, the bottom was dimensioned 1mm smaller, this ensured stability yet easy access to the wiring pins. Lightning bolt extrusions were added to match the aesthetic theme of the main body. The motors spin the wheels via direct contact drive, so the lightning bolts also served as a ledge to hold a counterweight we implemented in the final design. This counterweight was made from our prototype wheels as a casing, and broken DC motors as weights; this reduced wasted material. 

\begin{figure}[H]
    \centering
    
    \caption{Motor Hinge isometric view}
    \label{fig:Motorhinge}
\end{figure}

\subsubsection{Wheels}
Two variations of the wheel design were manufactured, thin and thick as shown on the left and right of Figure \ref{fig:Wheels} respectively. 50, 55, 60, 65, and 70mm diameter dimensions were trialled throughout the project. The final wheel on the robot was a 55mm thick wheel. The smaller diameter had a smaller moment of inertia, which required less torque to rotate whilst still being large enough so that the motor hinges did not interfere with the electronic components of the main PCB. 

\begin{figure}[H]
    \centering
    
    \caption{Thick and thin wheel design variations isometric view}
    \label{fig:Wheels}
\end{figure}

\subsection{Software}
A reactive controller was made using Arduino programming, code in Appendix A. The reactive control depended on the immediate feedback of 3 sensors, left, centre, and right, where each sensor was compared against a threshold value to detect if the sensor was on the line. The robot was placed with the line central to the centre sensor. The robot would turn left if the right sensor detected the line, right if the left sensor detected the line, and forward if the centre sensor detected the line. This closed-loop control system minimized the error of the distance from the line, providing a simple, robust and responsive method of following the line.  

\section{Results \& Discussion}
The software part of the line-following-robot started with high expectations of a working PID controller. However, our sensor boards had issues so only 2 sensor boards worked during the programming phase. This made PID control overly complex for our robot, so a reactive controller was made using Arduino programming, code in Appendix A. A limitation to having feedback from 2 sensors was the oscillations of the robot due to the sensors continuously triggering changes in direction without settling. This reduced the potential top speed of the robot. 
\\

To combat this, a third sensor positioned at the centre was added, and the robot moving forward when the sensor detected the line. By adding a third sensor, there was an average 4.9-second increase in course performance times, outlined in the ‘Course Times by Sensor Configurations and Weight’ table in Appendix B. This time saving was expected due to increased feedback allowing the sensors to occasionally settle in a forward state when the centre sensor detects the line. In doing so, the robot followed the line more smoothly, allowing for increased speeds. Therefore, to further reduce the average course time from a software perspective, a working PID and more sensors closely spaced together would be recommended. Weight was added to above the motors to increase the friction between the motors and wheels. Rough blotches of solder were also melted onto the motor shafts, which allowed it to grip the wheels better. Figure \ref{fig:Trialchart} shows the results of these optimisation changes. 

\begin{figure}[H]
    \centering
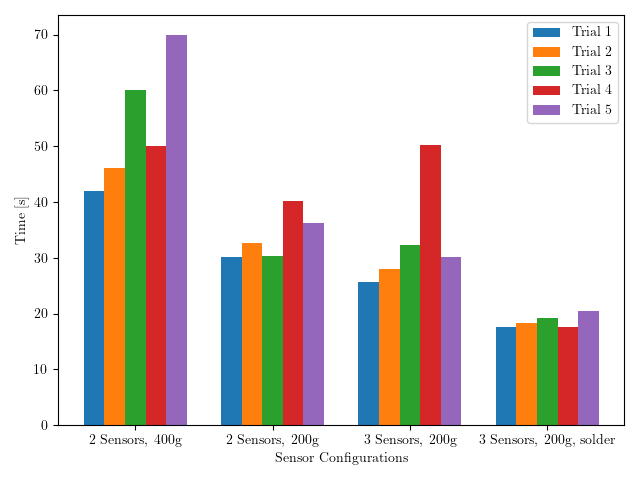
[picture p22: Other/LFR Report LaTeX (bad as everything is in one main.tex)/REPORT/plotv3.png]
    
    \caption{Line Following Robot Course Times by Sensor Configurations and Weight }
    \label{fig:Trialchart}
\end{figure}

The Line Following Robot performed competitively well in the final demonstration, finishing the course in 14.939 seconds on our first attempt. A video of the robot's final run can be accessed with the following link: \href{https://youtu.be/P_ezBJ8gyDk}{$https://youtu.be/P_ezBJ8gyDk$}. The robot tracked the line reasonably accurately, with only minor overshooting when trying to make turns, which was within an acceptable range. After the first trial, we attempted to move the sensors closer together to improve line detection accuracy and reduce overshooting, thereby increasing speed. However, this approach failed during testing due to interference between the sensors when they were positioned too close to each other. 
\\

Our second solution was to gradually increase the forward speed of the robot. However, this caused other issues, such as difficulty in maintaining accurate line detection, which led to increased deviations from the path and potential loss of control. The robot struggled to respond quickly enough to changes in the line’s direction, resulting in more frequent overshooting of turns and ultimately decreasing its overall performance and reliability in navigating the course. We tried several speed settings but couldn’t achieve a result better than our first trial. Due to time pressure, we were unable to conduct another trial. 
\\

Looking ahead, several solutions could yield better results. First, we could program an additional sensor, allowing the robot to utilize four sensors for improved line tracking and reduced overshooting. Secondly, we were using bang-bang control, which only has two states, on or off based on whether the robot is on or off the line. Transitioning to a PID control system could enhance performance. Proportional control would respond to the current error (the difference between the desired position, centred on the line, and the current position), integral control would address the accumulation of past errors to eliminate steady-state error, and derivative control would predict future errors based on the rate of change, helping to dampen the system and reduce oscillations. This approach could allow our robot to increase speed while following the line more accurately and with less overshooting during turns. 
\\

Moving forward from this project, we have gained a better understanding of the importance of real-world testing. If this project were to be repeated, we would allocate more time toward improving the design of the PCB board and conducting thorough software testing. 

\section{Conclusion}
 The Line Following Robot project involved circuit design, PCB layout, mechanical assembly, and control systems. While we encountered challenges, particularly with sensor board malfunctions and feedback control, the robot still performed well, completing the course in 14.939 seconds. By using a reactive control system, we were able to achieve consistent results, though transitioning to a PID control system could improve accuracy and make the robot’s movements smoother. This project emphasized the importance of testing and collaboration to work through design unpredicted errors. Moving forward, further improvements could be made by refining sensor placement, improving the control system, and optimizing the mechanical design. Overall, the project met its objectives and gave us practical experience in combining different areas of mechatronics engineering.

\newpage
\bibliographystyle{ieeetr}  % The style of the bibliography (e.g., plain, alpha, etc.) 
\bibliography{references}

\newpage
\appendix
\section{Arduino Code for Line Following Robot}
\subsection{Overview}
The code was programmed using Arduino. Only the .ino, .cpp and config.h files are included in Appendix B. For full code including .h files, access the GitHub: \href{https://github.com/blaketolmie/LFR}{https://github.com/blaketolmie/LFR}
\subsection{LFR\_Main.ino}

\begin{figure}[H]
    \centering
    
\end{figure}

\subsection{Motors.cpp}

\begin{figure}[H]
    \centering
    
\end{figure}

\subsection{Sensors.cpp}

\begin{figure}[H]
    \centering
    
\end{figure}

\subsection{LEDs.cpp}

\begin{figure}[H]
    \centering
    
\end{figure}

\subsection{Config.h}

\begin{figure}[H]
    \centering
    
\end{figure}

\section{Table for LFR Course Times by Sensor Configurations and Weight}
\begin{figure}[H]
    \centering
    
\end{figure}

\section{Allowed Electronic Components}
\begin{figure}[H]
    \centering
    
\end{figure}

\end{document}

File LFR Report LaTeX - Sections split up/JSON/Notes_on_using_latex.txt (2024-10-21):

To prevent text from going endlessly to the right in VS Code, you can enable word wrap. This will ensure that long lines of text wrap within the editor window, making it easier to read and edit your code.
Here’s how you can do it using the settings menu:
1. Go to File > Preferences > Settings (or press Ctrl + ,).
2. In the search bar, type word wrap.
    Set Editor: Word Wrap to on.
-------------------------------------------------------------------------------------------------------------------------------
Writing styles in latex (2 options)
- have includes to different sections (preferred) - do include{}'s for just the very large sections, leave abstract, introduction and conclusion in  main.tex
- one massive document where you navigate it using the vs code tex extension (messy and hard to navigate)
-------------------------------------------------------------------------------------------------------------------------------
Control s to save document, and auto build pdf. 
-------------------------------------------------------------------------------------------------------------------------------
Edit the JSON file so then all the messy files eg .aux go into a folder called aux_dir. First make aux_dir folder then edit JSON settings by ctrl and , then searching up 
-------------------------------------------------------------------------------------------------------------------------------
Viewing pdf
To view the pdf in a new window without clashes with vscode-pdf, 
    Open pdf > Right Click pdf in top horizontal files bar > Move into New window

Otherwise text pdf viewer clashes with vscode-pdf if you open in a new window with other methods, so would have to turn off vscode-pdf extension. This is the case if you get the example error image which indicates a compatibility issue between the “LaTeX Workshop” and “vscode-pdf” extensions in Visual Studio Code. To resolve this, you can disable one of the extensions. Here’s how:

Open Extensions View:
    Click on the Extensions icon in the Activity Bar or use Ctrl+Shift+X (Windows/Linux)
Locate the Extension:
    Search for “LaTeX Workshop” or “vscode-pdf” in the Extensions view.
    Disable the Extension:
        Click the gear icon next to the extension and select Disable.
-------------------------------------------------------------------------------------------------------------------------------

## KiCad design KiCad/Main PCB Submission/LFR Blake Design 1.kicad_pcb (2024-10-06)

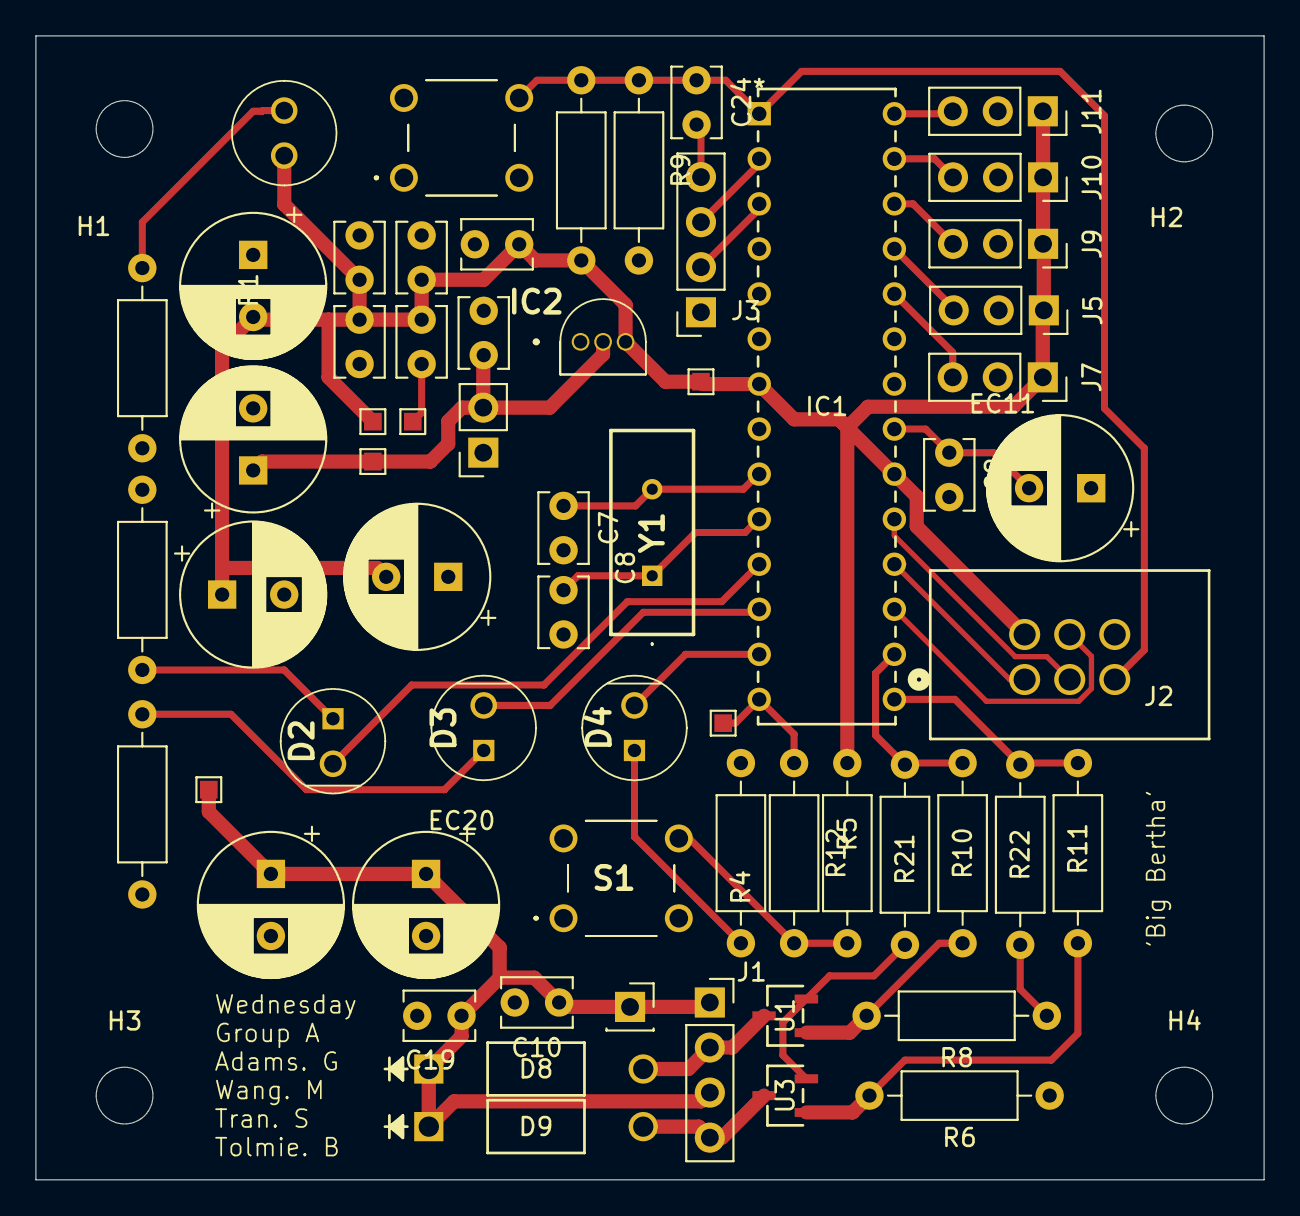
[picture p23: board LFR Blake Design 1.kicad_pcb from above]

Board: 2 copper layers, 69.2 x 64.5 mm, 66 parts (0 on the bottom side), 34 nets.

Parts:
C2, C3, C5, C9, C14: 100nF; C_Disc_D3.8mm_W2.6mm_P2.50mm
C7, C8: 20pF; C_Disc_D3.8mm_W2.6mm_P2.50mm
C10, C19: 100n; C_Disc_D3.8mm_W2.6mm_P2.50mm
C24: 0.1u; C_Disc_D3.8mm_W2.6mm_P2.50mm
Cm1, Cm2: 100nF; C_Disc_D3.8mm_W2.6mm_P2.50mm
D1: LED; 151051VS04000
D2, D3, D4: LED; 151051BS04000
D8, D9: 1N4004; Diode
EC1, EC4: 10uF; CP_Radial_D8.0mm_P3.50mm
EC11, EC16, EC17: 1uF; CP_Radial_D8.0mm_P3.50mm
EC20, EC21: 100u; CP_Radial_D8.0mm_P3.50mm
H1, H2, H3, H4: MountingHole; MountingHole_3.2mm_M3
IC1: ATMEGA328-PU; Microcontroller
IC2: MCP1700-3302E_TO; MCP17003302ETO
J1: Motor Inputs; PinSocket_1x04_P2.54mm_Vertical
J2: AVR-ISP-6; CONN_WR-BHD_61200621621_WRE
J3: Conn_01x04; PinSocket_1x04_P2.54mm_Vertical
J5, J7, J9, J10, J11: Conn_01x03; PinSocket_1x03_P2.54mm_Vertical
J6: Conn_01x02_Pin; PinSocket_1x02_P2.54mm_Vertical
J8: UnREG; PinSocket_1x01_P2.54mm_Vertical
R1: 360R; Throughhole Resistor
R2, R3, R4: 130; Throughhole Resistor
R5, R7, R21, R22: 10k; Throughhole Resistor
R6, R8, R10, R11: R; Throughhole Resistor
R9, R12: 1k; Throughhole Resistor
S1, S2: MJTP1230
TP1, TP1#2, TP3, TP4, TP5, TP6: TestPoint; TestPoint_Pad_1.0x1.0mm
U1, U3: BSR802NL6327HTSA1; Surface Mount MOSFET
Y1: HC-49_U-S9216000ABJB; HC49US9216000ABJB

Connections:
AVCC: C3.1, C5.1, C14.1, Cm1.1, Cm2.1, D1.2 (A), EC4.1, EC16.2, EC17.2, IC1.7 (VCC), IC1.20 (AVCC), IC2.3 (VOUT), J2.2 (VCC), J5.1, J7.1, J9.1, J10.1, J11.1, R5.2, R7.2, TP1.5 (1), TP3.1
GND: C2.2, C3.2, C5.2, C7.2, C8.2, C9.2, C10.2, C14.2, C19.2, Cm1.2, Cm2.2, EC1.2, EC4.2, EC11.1, EC16.1, EC17.1, EC20.2, EC21.2, IC1.8 (GND_1), IC1.22 (GND_2), IC2.1 (GND), J2.6 (GND), J3.1, J5.2, J6.1, J7.2, J9.2, J10.2, J11.2, R1.2, R2.2, R3.2, R4.2, R6.1, R8.1, R21.1, R22.1, S1.1 (COM_1), S1.4 (NO_2), S2.1 (COM_1), S2.4 (NO_2), TP1#2.1, U1.2, U3.2
MISO: IC1.18 (PB4_(MISO/PCINT4)), J2.1 (MISO)
MOSI: IC1.17 (PB3_(MOSI/OC2A/PCINT3)), J2.4 (MOSI)
MOTOR_CONTROL: IC1.14 ((PCINT0/CLKO/ICP1)_PB0), R12.1, TP4.1
Motor 1: IC1.15 (PB1_(OC1A/PCINT1)), R11.1, R22.2
Motor 2: IC1.16 (PB2_(SS/OC1B/PCINT2)), R10.2, R21.2
unnamed: D1.1 (K), R1.1
unnamed: D2.1 (K), R2.1
unnamed: D3.1 (K), R3.1
unnamed: D4.1 (K), R4.1
unnamed: D8.2 (A), J1.2, U1.3
unnamed: C10.1, C19.1, D8.1 (K), D9.1 (K), EC20.1, EC21.1, J1.1, J1.3, J8.1, TP5.1
unnamed: D9.2 (A), J1.4, U3.3
unnamed: IC1.2 ((PCINT16/RXD)_PD0), J3.3
unnamed: IC1.3 ((PCINT17/TXD)_PD1), J3.2
unnamed: C9.1, EC11.2, IC1.21 (AREF)
unnamed: C24.2, J3.4
unnamed: R8.2, R10.1, U1.1
unnamed: R6.2, R11.2, U3.1
unnamed: R5.1, R12.2, S1.3 (NO_1)
RESET: C24.1, IC1.1 ((PCINT14/RESET)_PC6), J2.5 (~RST), R7.1, R9.1, S2.3 (NO_1)
SCK: IC1.19 (PB5_(SCK/PCINT5)), J2.3 (SCK)
STAT1: D2.2 (A), IC1.11 ((PCINT21/OC0B/T1)_PD5)
STAT2: D3.2 (A), IC1.12 ((PCINT22/OC0A/AIN0)_PD6)
STAT3: D4.2 (A), IC1.13 ((PCINT23/AIN1)_PD7)
Sensor1: IC1.28 (PC5_(ADC5/SCL/PCINT13)), J11.3
Sensor2: IC1.27 (PC4_(ADC4/SDA/PCINT12)), J10.3
Sensor3: IC1.26 (PC3_(ADC3/PCINT11)), J9.3
Sensor4: IC1.25 (PC2_(ADC2/PCINT10)), J5.3
Sensor5: IC1.24 (PC1_(ADC1/PCINT9)), J7.3
UnREG: C2.1, EC1.1, IC2.2 (VIN), J6.2, TP6.1
XIN: C7.1, IC1.9 ((PCINT6/XTAL1/TOSC1)_PB6), Y1.2
XOUT: C8.1, IC1.10 ((PCINT7/XTAL2/TOSC2)_PB7), Y1.1

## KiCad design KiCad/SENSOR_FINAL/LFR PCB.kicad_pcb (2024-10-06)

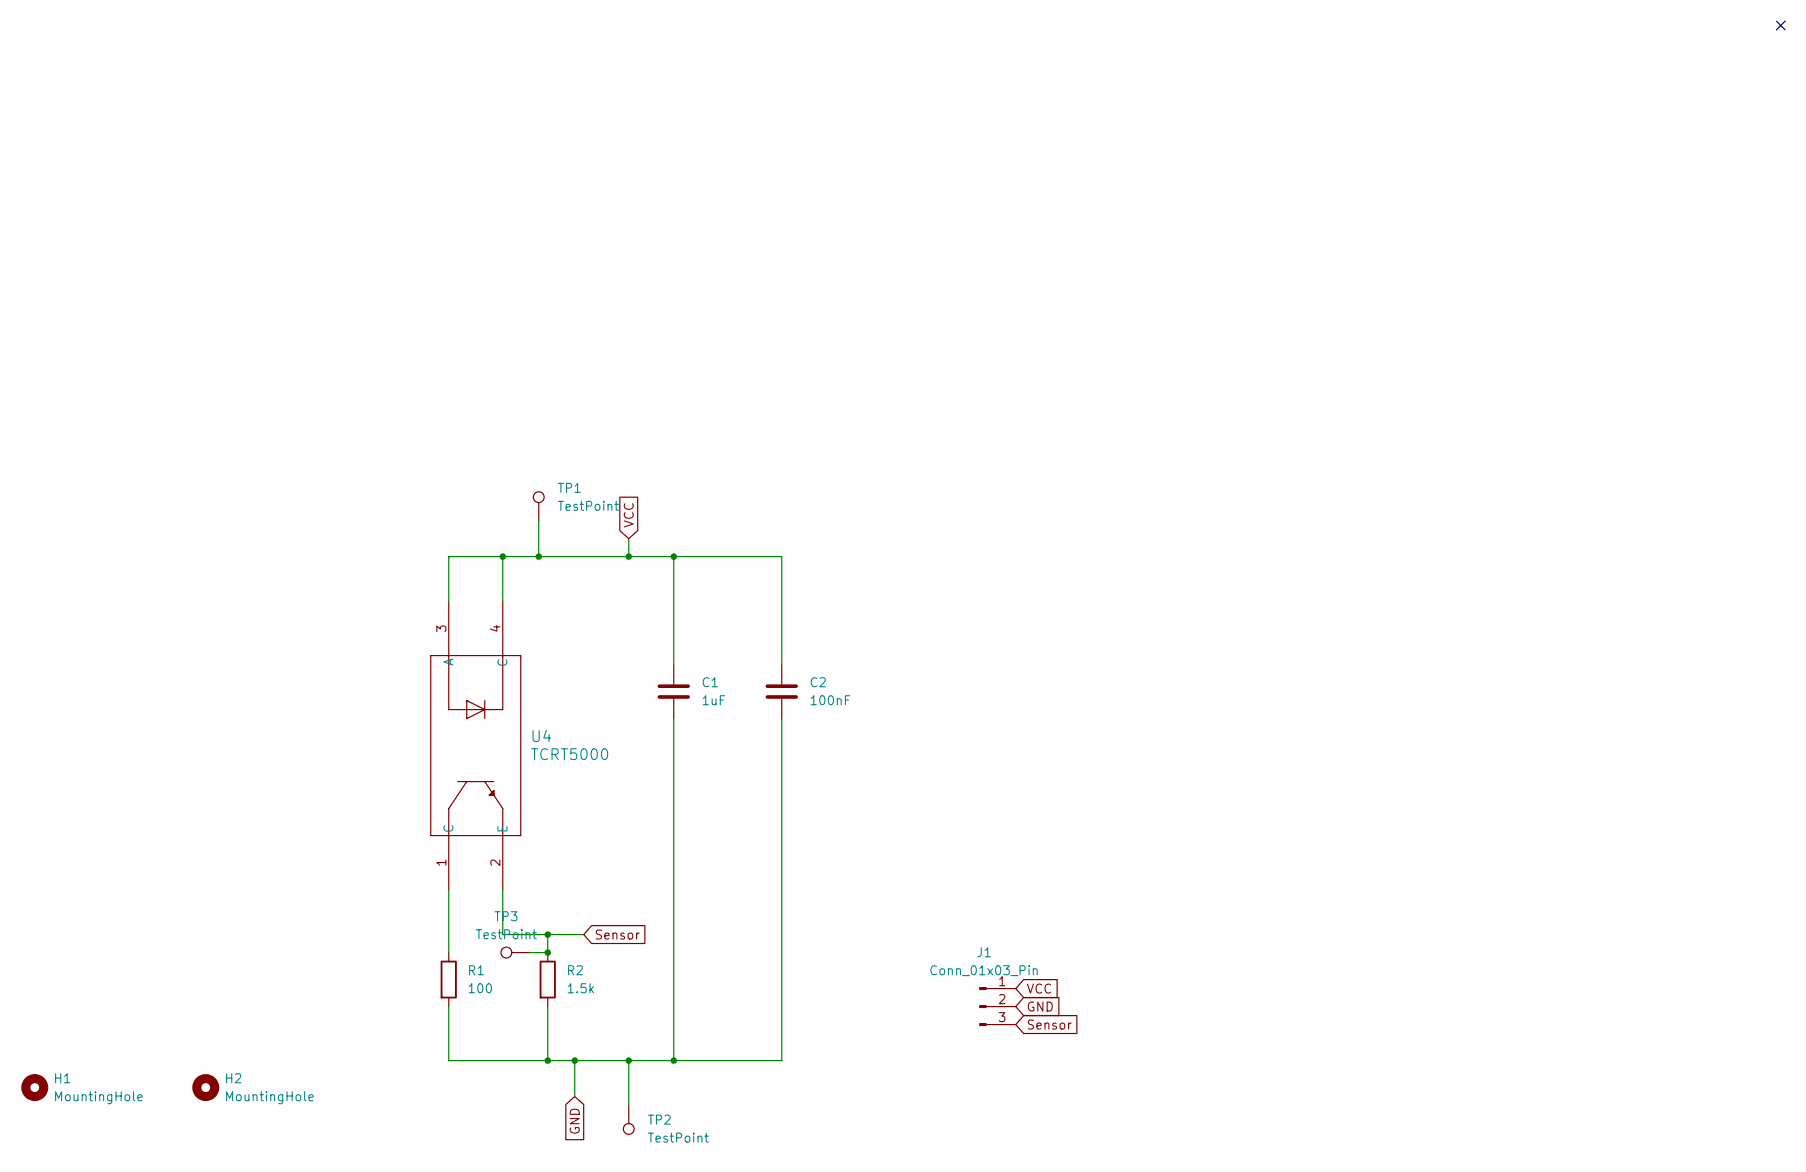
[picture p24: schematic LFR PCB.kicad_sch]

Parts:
C1: 1uF; C_Disc_D3.8mm_W2.6mm_P2.50mm
C2: 100nF; C_Disc_D3.8mm_W2.6mm_P2.50mm
H1, H2: MountingHole; MountingHole_3.2mm_M3
J1: Conn_01x03_Pin; PinSocket_1x03_P2.54mm_Vertical
R1: 100; Throughhole Resistor
R2: 1.5k; Throughhole Resistor
TP1, TP2, TP3: TestPoint; TestPoint_Pad_3.0x3.0mm
U4: TCRT5000; Sensor

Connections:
GND: C1.2, C2.2, J1.2, R1.2, R2.2, TP2.1
unnamed: R1.1, U4.1 (C)
Sensor: J1.3, R2.1, TP3.1, U4.2 (E)
VCC: C1.1, C2.1, J1.1, TP1.1, U4.3 (A), U4.4 (C)

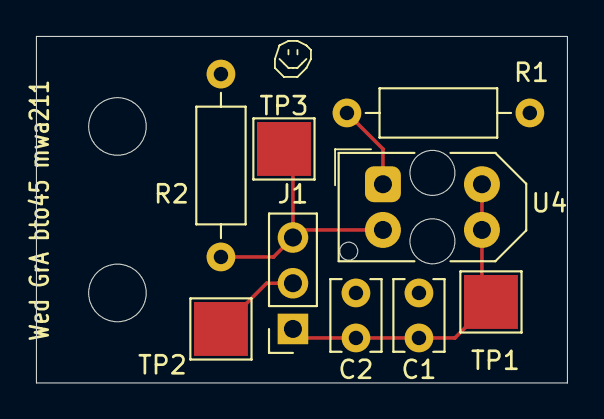
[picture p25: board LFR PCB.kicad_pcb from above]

Board: 2 copper layers, 29.5 x 19.2 mm, 11 parts (0 on the bottom side), 4 nets.

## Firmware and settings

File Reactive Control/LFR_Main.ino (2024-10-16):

#include "config.h"
#include "Motors.h"
#include "LEDs.h"
#include "Sensors.h"

int16_t threshold = 230;      // Threshold for sensors on main course
int16_t speed_up = 70;        // Motor speeds
int16_t slow_down = 0;
int16_t forward = 30;
int16_t left_speed = 65;      // Starting motor speeds
int16_t right_speed = 65;

void setup() {
    initStatLEDs();
    initMotors();
    initSensors();
}

void loop() {
    // Read sensor values
    int16_t sensor_1 = analogRead(SENSOR_1);
    int16_t sensor_3 = analogRead(SENSOR_3);
    int16_t sensor_5 = analogRead(SENSOR_5);

    if (sensor_3 < threshold) {
      // Forward
        left_speed = (speed_up-10);
        right_speed = (speed_up-10);
    } else if (sensor_1 < threshold) {
        // If the left sensor senses the line, turn left by increasing speed of right motor etc
        left_speed = speed_up;
        right_speed = slow_down;
    } else if (sensor_5 < threshold) {
        // If the right sensor senses the line, turn right by increasing speed of left motor etc
        left_speed = slow_down;
        right_speed = speed_up;
    }

    setMotorSpeed(left_speed,right_speed);

    // LED sensor indicators
    if (sensor_1 < threshold) {   // sensor 1 sensing line
      turnOnLED(LED_1);
    } else {
      turnOffLED(LED_1);
    }
    if (sensor_3 < threshold) {   // sensor 3 sensing line
      turnOnLED(LED_2);
    } else {
      turnOffLED(LED_2);
    }
    if (sensor_5 < threshold) {   // sensor 5 sensing line
      turnOnLED(LED_3);
    } else {
      turnOffLED(LED_3);
    }
}

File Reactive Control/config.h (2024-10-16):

#ifndef CONFIG_H
#define CONFIG_H

#include <Arduino.h>

// Motor speed limits
#define MAX_MOTOR_SPEED 255     
#define MIN_MOTOR_SPEED 0

// Pins
// https://camo.githubusercontent.com/b719fa994f4db0dd95e224fbdd939f93f7b6ba881b3c41e480b4733d4d82b6e6/68747470733a2f2f692e696d6775722e636f6d2f715849456368542e6a7067

#define LED_1 5    // LEDs are on pins 5,6,7 on Arduino 
#define LED_2 6
#define LED_3 7

#define MOTOR_CONTROL 8
#define LEFT_MOTOR 9
#define RIGHT_MOTOR 10

// Define the sensor pins (ADC channels)
#define SENSOR_1 A1            // Left sensor
#define SENSOR_2 A2
#define SENSOR_3 A3            // Middle sensor
#define SENSOR_4 A4
#define SENSOR_5 A5            // Right sensor

#endif

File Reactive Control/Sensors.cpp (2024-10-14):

#include "Sensors.h"

int16_t sensorValues[10];
// Initialize the sensor pins
void initSensors() {
    pinMode(SENSOR_1, INPUT);
    pinMode(SENSOR_2, INPUT);
    pinMode(SENSOR_3, INPUT);
    pinMode(SENSOR_4, INPUT);
    pinMode(SENSOR_5, INPUT);
}

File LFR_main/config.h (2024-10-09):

#ifndef CONFIG_H
#define CONFIG_H

#include <Arduino.h>

// PID constants / tuning
const float Kp = 2.0;  // Proportional constant
const float Ki = 1.0;  // Integral constant
const float Kd = 1.0;  // Derivative constant
const int16_t INTEGRAL_LIMIT = 100; // Integral windup limit

// Key constraints
#define SETPOINT 255             // Setpoint for the middle sensor (ideally 255 or 0 - depending on what you want to sense)
#define MAX_MOTOR_SPEED 255     // Motor speed limits
#define MIN_MOTOR_SPEED 0

// Pins
#define LED_1 11    // LEDs are on pins 11,12,13
#define LED_2 12
#define LED_3 13

#define MOTOR_CONTROL 14
#define LEFT_MOTOR 15
#define RIGHT_MOTOR 16


// Define the sensor pins (ADC channels)
#define SENSOR_1 24
#define SENSOR_2 25
#define SENSOR_3 26            // Middle sensor
#define SENSOR_4 27
#define SENSOR_5 28
#define SENSOR_COUNT 5         // Number of sensors

#endif

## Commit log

2024-10-06 Adding KiCad files
    [LFR Blake Design 1-B_Cu.gbr, LFR Blake Design 1-B_Mask.gbr, LFR Blake Design 1-B_Silkscreen.gbr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]
2024-10-06 Changed to Arduino Programming
    Instead of doing C changed it to Arduino programming using ChatGPT so need to fix bugs and pin numbers etc
2024-10-06 update with correct pin numbers
2024-10-06 Organized folders
    [LFR Blake Design 1-B_Cu.gbr, LFR Blake Design 1-B_Mask.gbr, LFR Blake Design 1-B_Silkscreen.gbr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]
2024-10-08 Made it so then it works using Arduino IDE
    Needed to rename and move files so then all the .cpp and .h files open in Arduino IDE
2024-10-14 moved pid code into old code folder
2024-10-14 updated set motor speed to include constraining speed
2024-10-15 WORKING VERSION - 2 Sensors
2024-10-21 removed old PID
2024-10-21 folder reshuffle
    [LFR Blake Design 1-B_Cu.gbr, LFR Blake Design 1-B_Mask.gbr, LFR Blake Design 1-B_Silkscreen.gbr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]
